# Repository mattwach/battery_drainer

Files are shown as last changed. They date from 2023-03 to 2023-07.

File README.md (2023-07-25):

# battery_drainer

This project describes hardware to safely discharge batteries to a user-chosen
level.

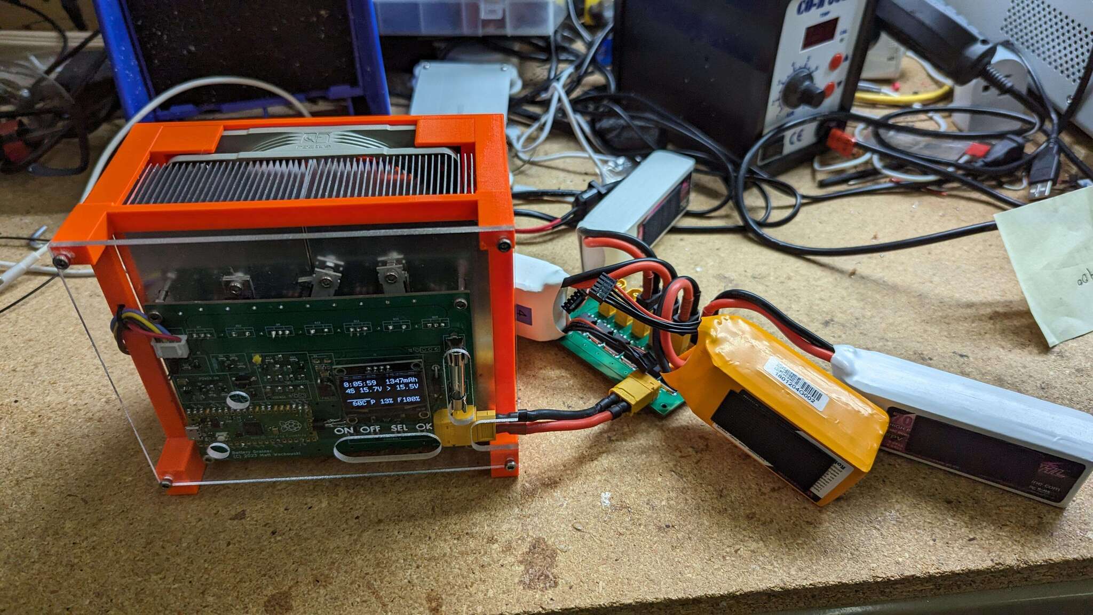
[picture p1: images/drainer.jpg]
Drainer


# Why?

Before I started flying RC models (many years ago), the concept of managing
batteries was off my radar.  While in the hobby, it became clear that proper
management makes a big difference in how long batteries last and how much power
they will deliver.

Storing lithium ion batteries fully-charged or fully-drained causes them to
degrade permanently.  It's much better to store them in a half-charged state.

Since lithium batteries are used basically everywhere (phones, tools, laptops,
    cars, on and on), being aware of these concepts can help you keep more of
your devices running longer and more healthy.

Many non-lithium batteries have "memory effects" and can benefit from a deep
discharge now and then.  See your particular battery type for details on how to
maintain/restore it.

Other applications for discharging include testing battery capacity and
preparing it for disposal.

# Caution

Following anything written in this document is at-your-own risk.

Batteries are energy storage devices and thus carry an inherent risk.  If you
are not familiar with the battery type you are working with, take a few moments to
educate yourself on recommended handling practices.

When working with an untested unit or new batteries, I suggest extra caution.
For example doing initial testing outside on concrete or in a fire pit.

This design incorporates a protection fuse.  I recommend using the
*smallest-sized fuse* that meets your requirements.  If anything goes wrong
with the firmware, a hardware component, or the hardware build, the fuse will
limit the maximum current that can flow.  Starting with a small fuse and
upgrading it later could be a good verification strategy.

# Pre-existing Market Solutions

If you look up "LIPO Battery Discharger" on Amazon or similar, you will find a
variety of products.  These might work for you but note that the project I am
describing has some advantages over what you can buy:

1. Higher maximum power.  The unit I built is running great at 350W.  The components
   I chose are speced to 460W and 30A.  Since you are building it yourself,
   you can choose a transistor/cooling combo that supports the power dissipation
   you need.
2. Support for "safe" multiboards.  My project has a diode-protected multiboard
   that allows you to safely plug in multiple batteries that are at different 
   discharge levels. This protection requires the discharger account for the 
   voltage drop across the protection diodes, which commercial charges do not
   typically do.
3. Support of 1S packs.  Many chargers have a 2S minimum.
4. Lots of customization.  My project lets you customize voltages and
   create special profiles.  For example, I have one that takes packs down to
   4V/Cell, which is useful for packs that I want ready-to-use in worklights and tools.
5. Detailed status.  The OLED of this project gives lots of information
   during the discharge which can help you guage the health of the pack.
6. Support for more battery types than just LIPO, due to the extensive 
   customization ability.

# Using

## User Interface

The unit has four UI buttons: On, Off, Select and OK.

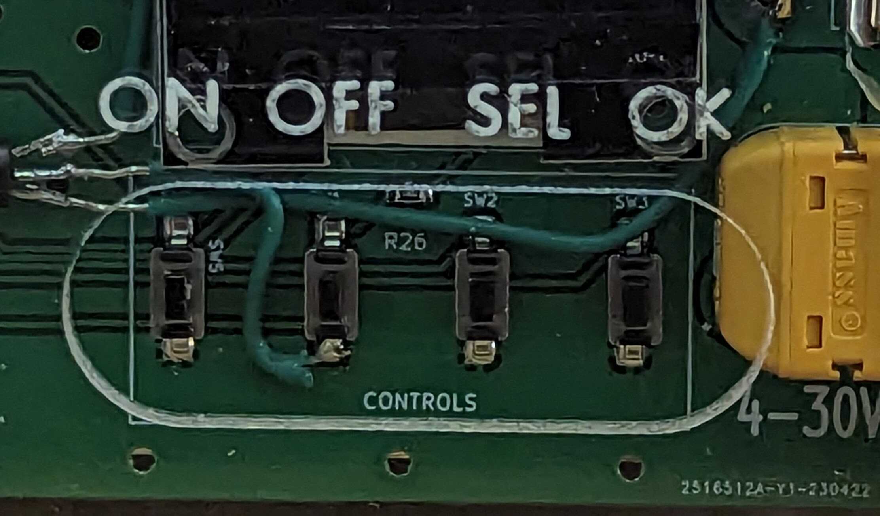
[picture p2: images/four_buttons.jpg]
four buttons


When the device is initially powered up, it will display the current voltage,
cell count and the target voltage.  It also shows a scrollable list of
profiles to choose from:

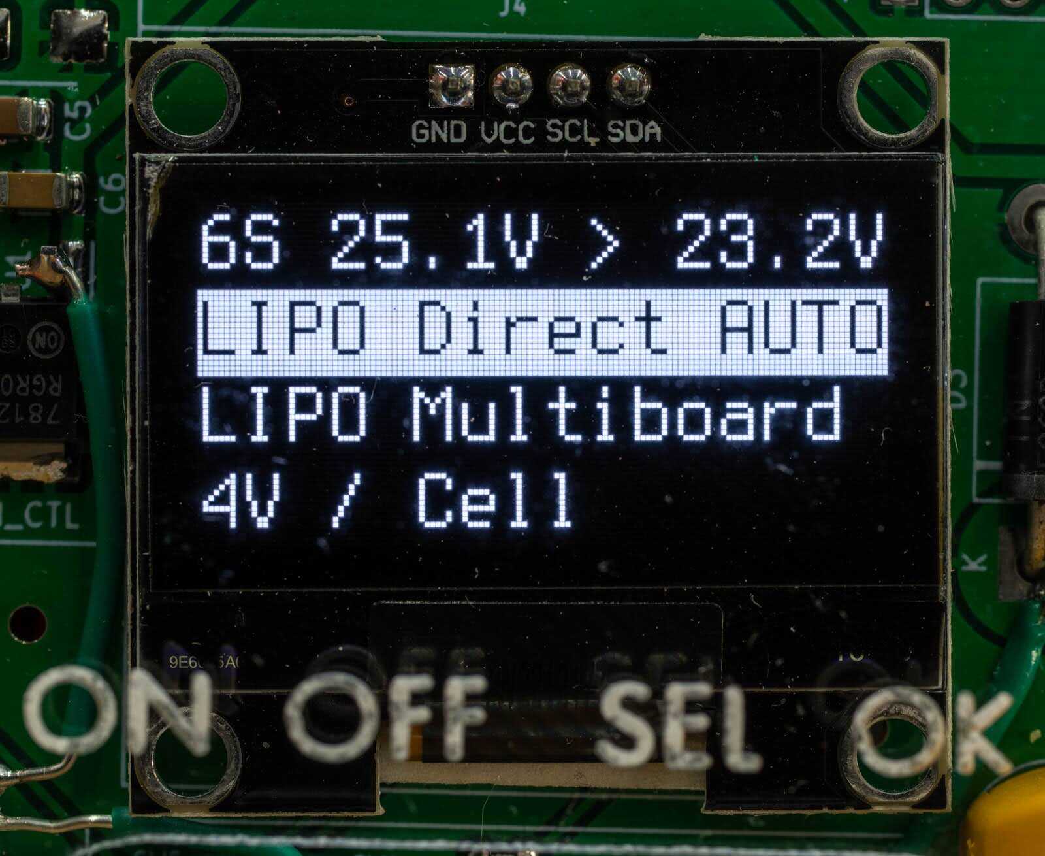
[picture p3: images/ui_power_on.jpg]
ui power on


The user chooses a profile with "Select" and presses "OK" to start discharging.
During discharge, the following status information is displayed (the ghosting
in the image is because the unit was actively updating during the photo):

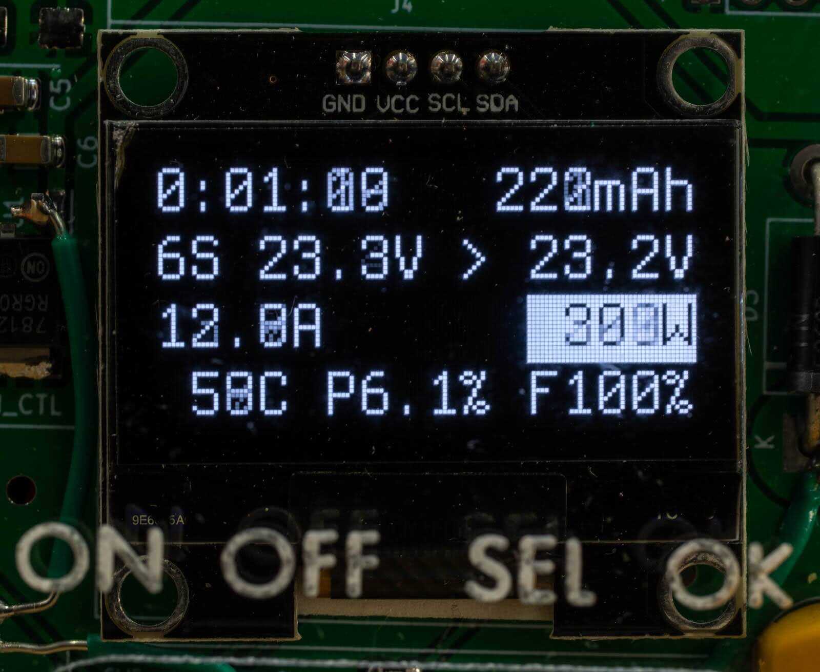
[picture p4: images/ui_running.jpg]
ui running


Information shown includes:

* Time running
* Number of mAH discharged so far
* Battery voltage and cell count
* Target voltage
* Discharge Current
* Power (Voltage * Current)
* Temperature
* FET power level %
* Fan power level %

If the FET power level is limited < 100%, then the parameter that is limiting
the power is highlighted as inverse text.  In the example above, this limit is
overall power draw.  A lower-cell-count battery might hit the max current
instead.  A small battery might be limited by voltage sag.  A hot day might
introduce a temperature limit.  All limits are user configurable - but you'll
need to be aware of what your built hardware can handle and test higher limits
with due caution.

When the discharge is complete, the unit will show some stats for a configurable
amount of time before automatically shutting down.  Here is an example:

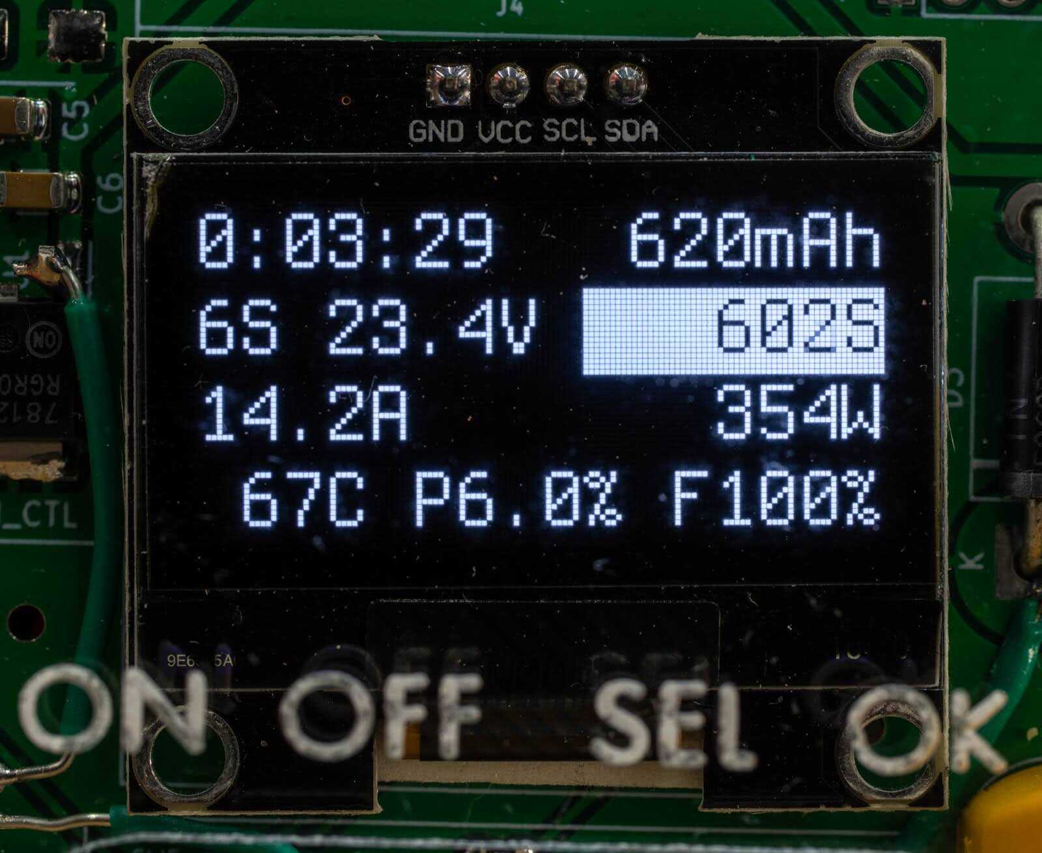
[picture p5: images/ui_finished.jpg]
ui finished


After shutdown, the unit takes very little power (a few microamps) to avoid
further unintended drainage of smaller packs.

## Configuration

Profiles can be edited by connecting a computer to the unit via USB and starting
a terminal program.  On my Linux laptop, I used:

    minicom -b 115200 -P /dev/ttyUSB0

Refer to the [dedicated configuration guide](configuration.md) for details
about how to configure settings, calibrate the device and create/edit profiles.

# Building

## Parts list

To see the parts list, open up the schematic in KiCad and look at the "Symbol
Fields Table".  It looks like a spreadsheet icon in the UI.  Here you will find
a list of parts and links for building an order.  Here is a snapshot of what
the list looked like at some point:

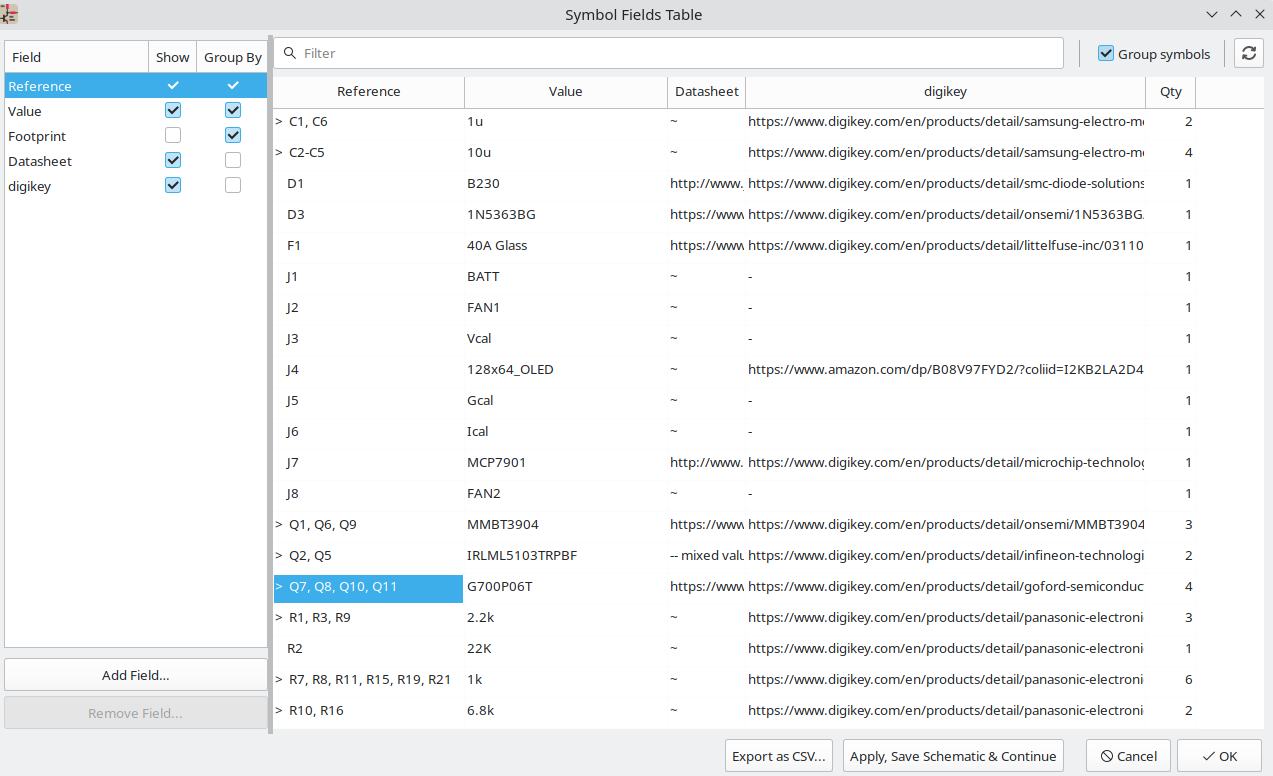
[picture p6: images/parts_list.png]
parts list


## Schematic Overview

Note that the images below are a snapshot of the schematic and not fully
up-tp-date.  See the KiCad original for the latest design.

Here is the complete design (click to expand):

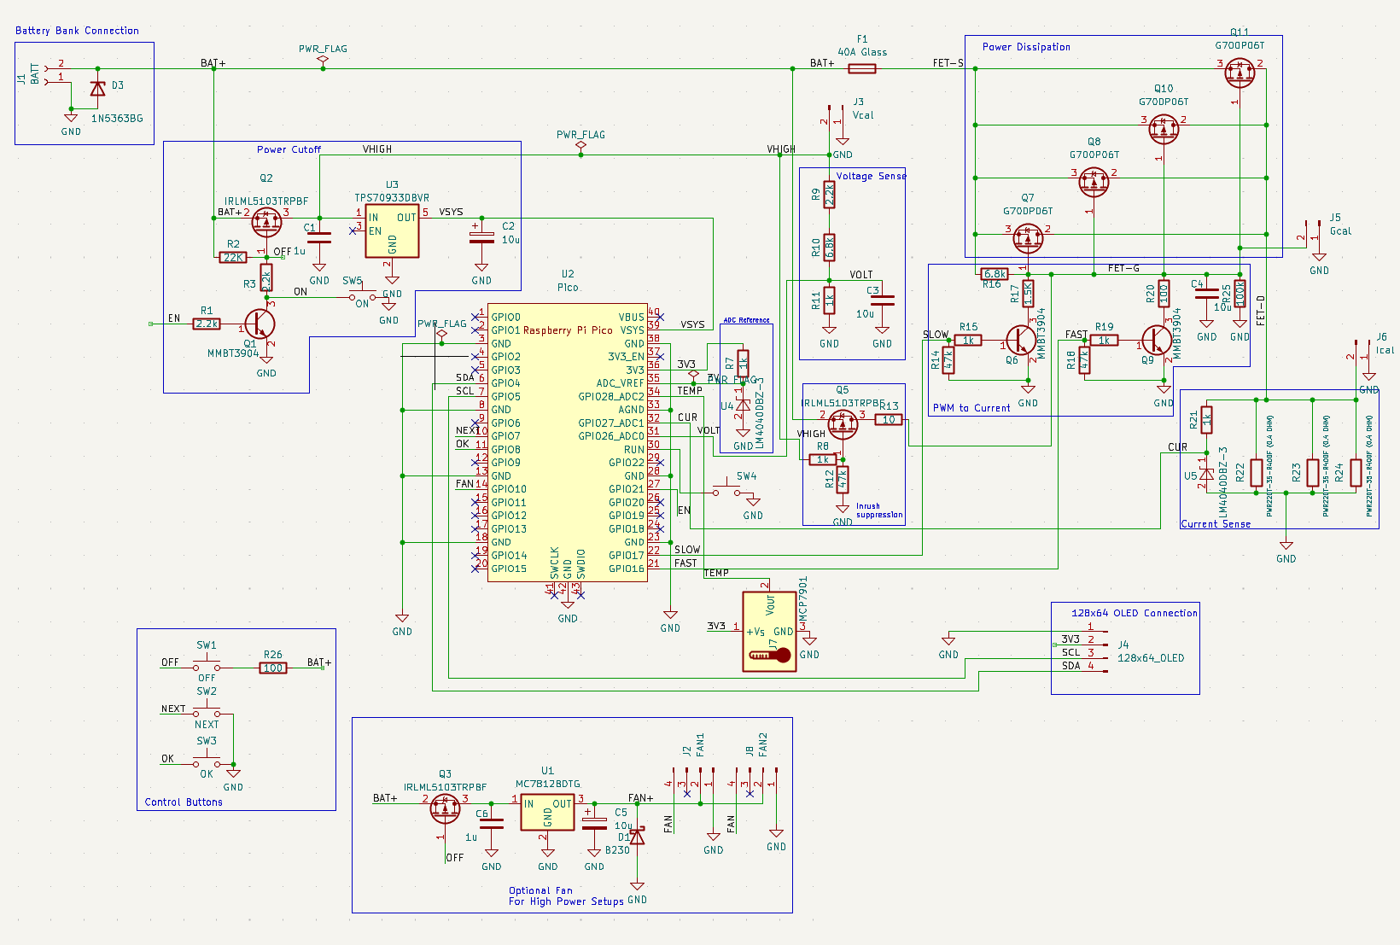
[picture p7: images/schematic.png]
schematic


Here is an early Falstad simulation that gives a basic idea of how the circuit
works:

https://tinyurl.com/2qg4xwyj

There is much going on here.  The sections below break down and explain one
subcircuit at a time.

### Power Dissipation

[Falstad model](https://tinyurl.com/28p9fv3n)

This is a set of 4 P-Channel MOSFETs connected in parallel:

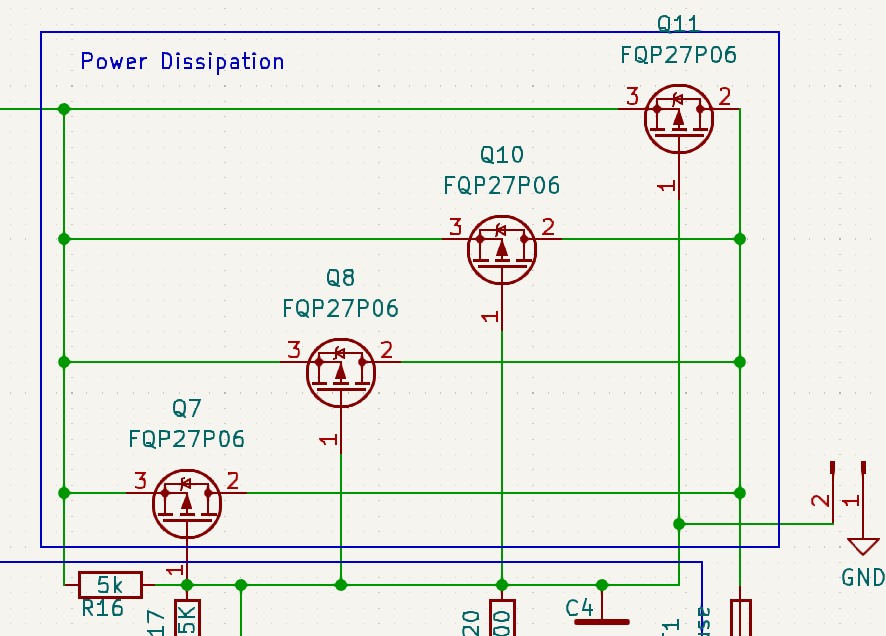
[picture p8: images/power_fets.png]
power FETs


More or less *could* also work.

**Note** The schematic shows four PFETs in parallel.  The unit *I actually
built* uses a single high-power FET instead.  I think that four PFETs would
still work but have not confirmed it.  The main risk of using 4 is that they
will be unevenly loaded to the point where one of them is damaged.  I do
believe that they will be unevenly loaded at lower currents but not after the
current ramps up enough to matter.  Again, I have not confirmed this.  Using a
single high-power FET is my recommendation if you want to play it safer.

The FETs in this design are (unusually) run in their "Ohmic" region which
is controlled by the gate-to-source voltage (Vgs) as exampled in the FQP27P06
datasheet graph below:

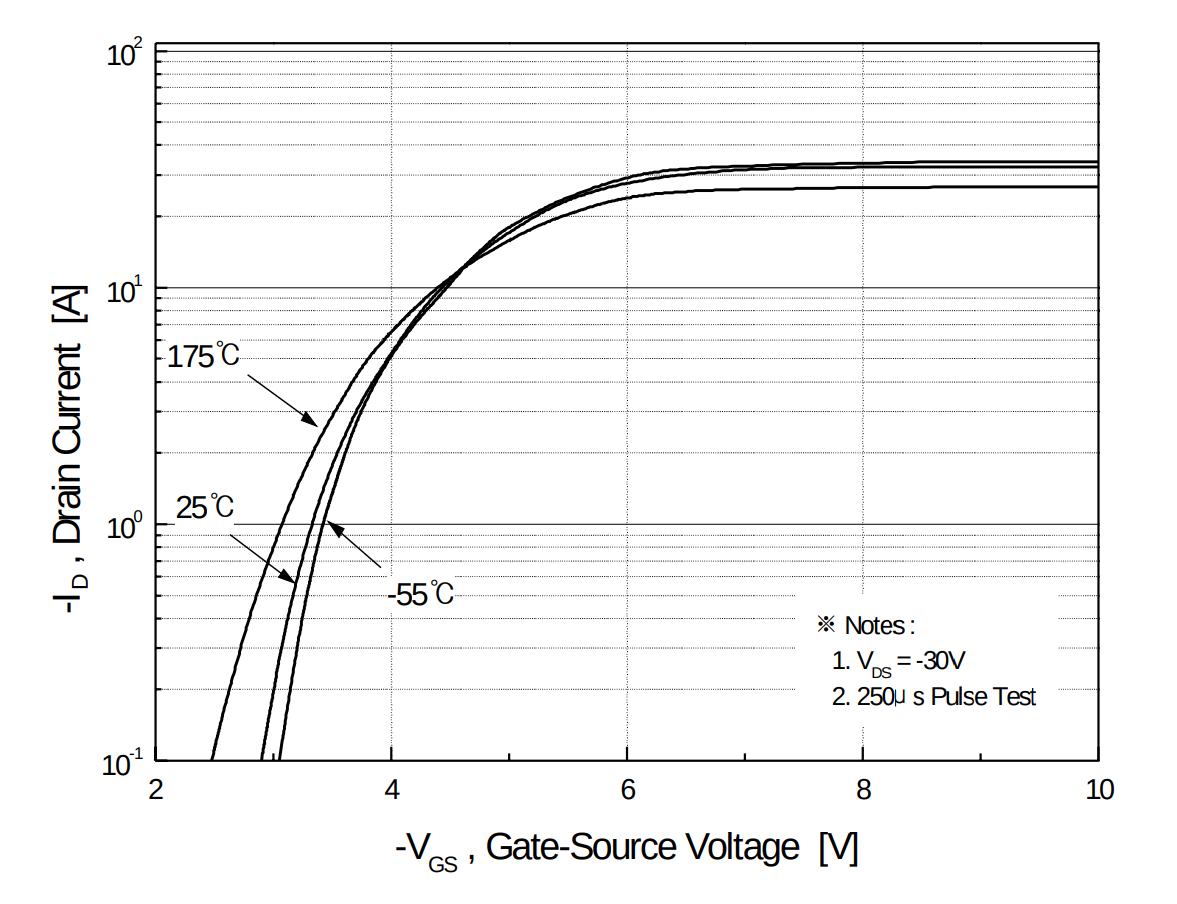
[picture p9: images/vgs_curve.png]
vgs curve


### Vgs Control

[Falstad model](https://tinyurl.com/2bj46fut)

To achieve the target Vgs for the FETs, we the following circuit:

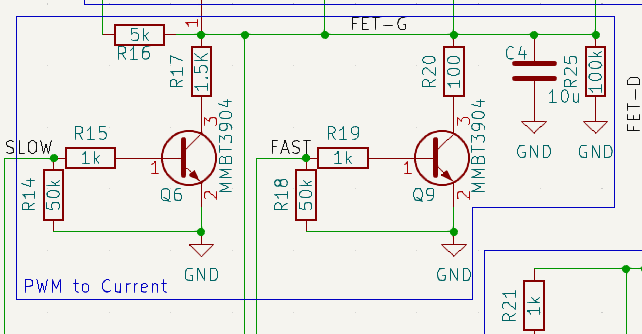
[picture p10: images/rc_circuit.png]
rc circuit


The main element here is the 10u capacitor on the right side of the image.
The voltage across this capacitor is the gate voltage that
each FET will see.

Filling the capacitor is the 5k resistor, R16.  If only this resistor and the
capacitor existed, then the RC constant would be 5000 * 10e-6 = 50ms.  When the
capacitor is sufficiently charged, the FETs will be turned off.

The two transistors (Q6, Q9) are used to drain the capacitor.  The one on the
left is a "slow" drain and the one on the right is a "fast" drain.  The size of
the resistors (R17 and R20) determines the drain speed.  A microcontroller
feeds in a PWM to open/close the transistor.  The duty cycle of this PWM
signal determines how much current is pulled on average and the frequency
of this PWM signal determines how smooth/stable the voltage will be.

The reason for two drains (verses one) is to support a larger voltage
range.  At lower voltages (4V), the FAST drain circuit is needed
to get the Vgs lower than the SLOW drain can achieve.  For higher voltages
(25V), the SLOW drain provides better control resolution.  Depending on the
FET you go with and voltage range you want to support, a single drain
may work fine.

In the power-on state, we can assume that SLOW and FAST are not driven at all
(high Z).  In this state the two 50k pulldown resistors (R14, R18) turn off Q6
and Q9 causing the capacitor to fill up and turn off the main power FETs.

The 100K pull down resistor (R25) slowly drains the capacitor so that it at a known
voltage (0V) when the unit is unplugged and idle.

## Inrush protection

[Falstad model](https://tinyurl.com/2y8c54c8)

On initial battery plug-in, the 100ms or so it takes the capacitor (C4) to
charge via R16 could allow a high current to pass through the FETs for that
time period.  This is mitigated by the following inrush protection circuitry:

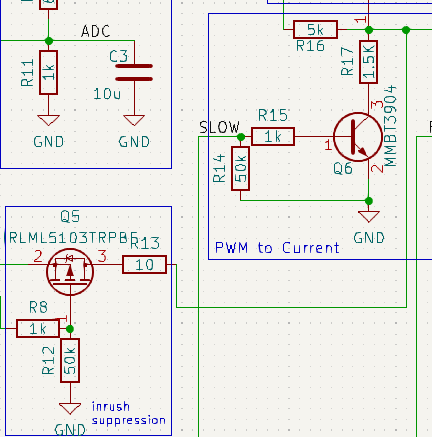
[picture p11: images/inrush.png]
inrush


Fully understanding this block will require studying the full schematic.  A
partial understand can be gained from the image above and the Falstad model.  We
basically have another way to fill the capacitor C4 which is "enabled" when the
battery is plugged in but the user has not pressed the power button yet.  The
way this works is that the source of the FET Q5 is connected to the battery
and the small 10 ohm R13 allows for a rapid fill.  R8 is connected to the
microcontroller power and is thus grounded on plug-in, turning "on" the
FET.

When the user powers on the device (after the battery is plugged in), there is
voltage near-battery going to R8 which turns off the FET and cuts off R13.

### Current Sense 

[Falstad model](https://tinyurl.com/253e6aln)

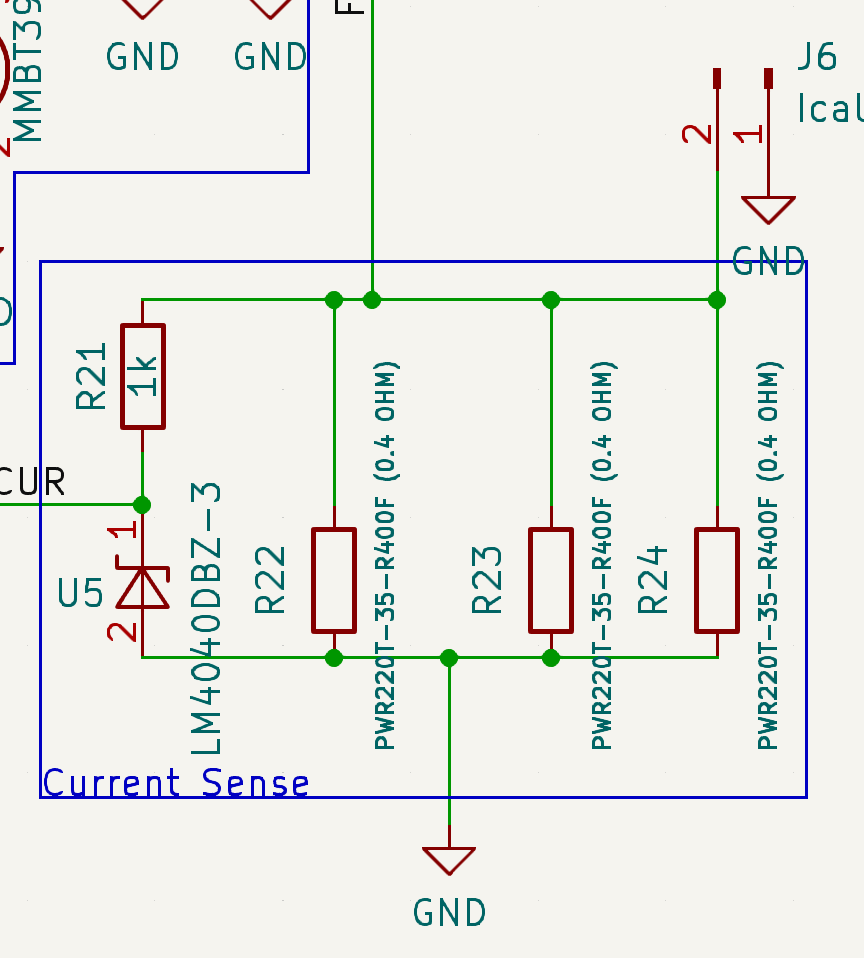
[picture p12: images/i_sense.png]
i sense


One of the four ways the microcontroller decides where to set Vgs is by
monitoring the current flowing through the FETs  (the other three are voltage,
power, and temperature).  An ADC within the microcontroller measures the voltage
across the resistors (R22-R24) then uses Ohm's law (I = V/R) to determine the
current.

Resistor values were chosen for a full 3V swing at 30A of current, this allows
us to use the full 12-bits of ADC resolution for good accuracy.  The downside
is that 3V * 30A = 90W, which is a lot for a resistor to dissipate.  To support
this, I chose 3 35W 0.4 ohm resistors connected in parallel for a total dissipation
capability of ~100W and an equivalent resistance of 0.133 ohm.  Potentially
wasting this much power on a current measurement would normally be frowned upon but
in this application it's actually helping take some load off the main power FET.

A Zener diode (U5) is used to protect the ADC of the microcontroller in the
event that the divided voltage is too high (> 3V).  This is a protection
feature that serves no function under "normal" operating conditions.

### Protection Fuse

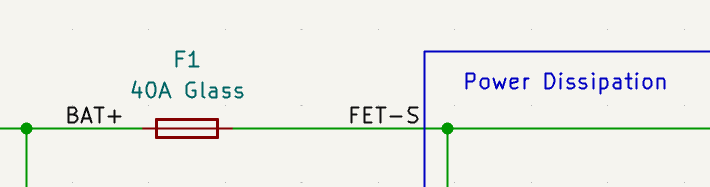
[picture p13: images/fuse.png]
fuse


We also have a protection fuse to help protect against software bugs or other
unexpected problems.  More protection would be offered if the fuse were right at
the battery input but this would introduce a further temperature-dependent
voltage drop that would throw off the voltage measurement.  The "unprotected"
components are the digital logic which should be low current draw barring a
physical issue with the board (< 100 mA)

### Voltage Sense

[Falstad model](https://tinyurl.com/2aavu5hb)

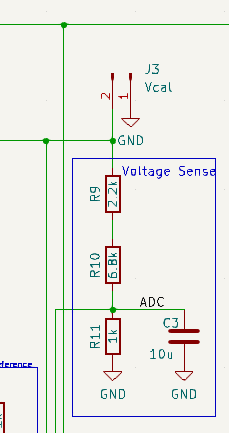
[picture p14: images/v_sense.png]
v sense


The microcontroller monitors the overall battery voltage to determine a sag
value and to determine when the drain process is completed.

The circuit is a simple voltage divider with a capacitor to help stabilize the
reading.

Sag is determined by periodically turning off the FETs (say for one second every
15 seconds) and measuring the "unloaded" voltage of the pack.  This can then be
used a reference value to determine the sag.

The voltage at R9 is not exactly the battery voltage as it has to pass through a
a diode and FET.  The software provides a calibration value to account for this
drop.

### Temperature Sense

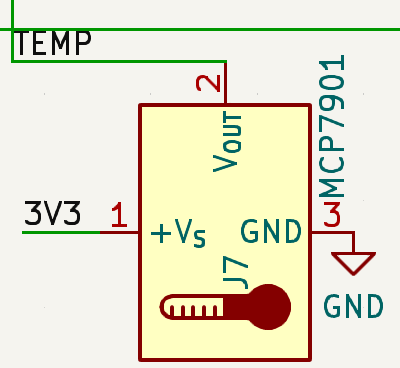
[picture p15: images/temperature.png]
temperature


A temperature sensor is placed against the heatsink and as-close-as-possible to
the FET to monitor the FET temperature.  This feedback can be used to control a
cooling fan (described below) and, if this is inadequate, reduce the current draw.

### Power cutoff

[Falstad model](https://tinyurl.com/22wuu5mp)

The battery drainer is designed to draw nearly zero power (outside of parasitic
losses) when it is off, including after the discharging has completed.  Thus the
user can leave the unit unattended (assuming the needed precautions have been
taken) without concern of parasitic drain.

This is implemented with the following circuit:

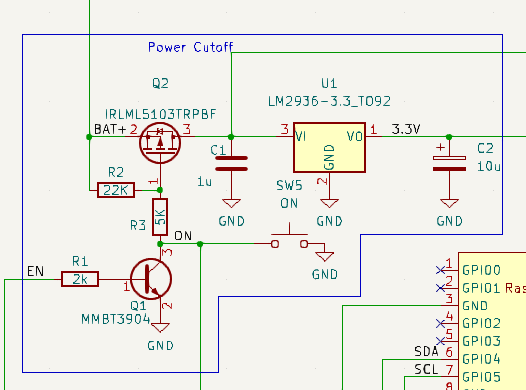
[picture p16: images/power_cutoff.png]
power cutoff


The Q2 FET is key.  It determines if the microcontroller gets any power.
Q2 is off by default, turned off by R2.  There are two ways to turn it on:

1. If the user presses SW5
2. If the microcontroller activates Q1 via "EN".  The microcontroller does
   this as soon as it can (in a split second) and holds it high until the
   microcontroller decides that it is time to power down OR the user presses
   the "OFF" button which forces Q2 off.

### ADC reference

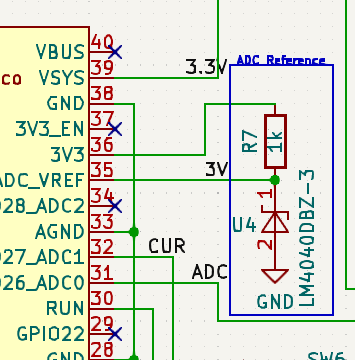
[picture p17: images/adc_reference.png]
adc reference


When using an ADC, one can typically choose from several different sources for
the calibration with the internally-generated 3.3V source as the most
convenient.  The downside of choosing this source is mediocre accuracy.

This design uses the alternate `ADC_VREF` input with a `LM4040` voltage reference
to allow for more accurate measurements.

### OLED connection

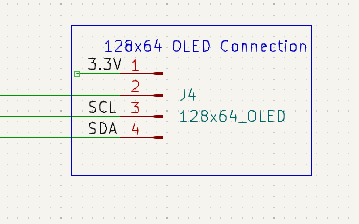
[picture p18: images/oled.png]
OLED


The design breaks out an I2C 4 pin header that is typical for an I2C OLED.  A
128x64 design is the intended unit but anything that supports I2C could be
supported with appropriate firmware modifications.

### Fan connection

The battery drainer effectively converts battery energy to heat, thus you'll need
a cooling strategy to avoid overheating and damaging the discharge circuit.
Like cooling other devices such as CPUs and GPUs, a passive solution is
sometimes adequate and an active solution is often needed.

The circuitry below supports a PWM-based fan controller.

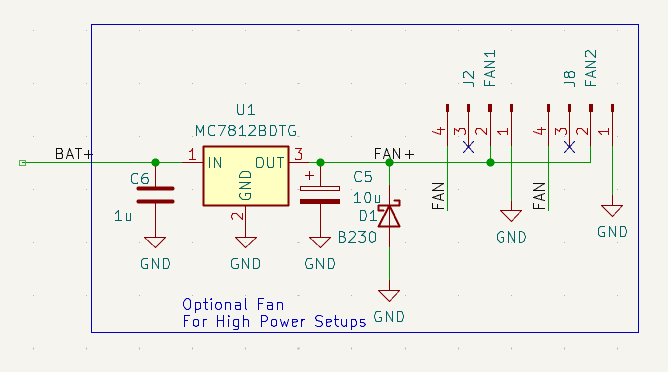
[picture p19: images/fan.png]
fan


The circuit is just a 12V linear regulator with supporting capacitors.  The
connections support "PWM" style PC case fans which generally accept a 25Khz
PWM signal on pin 4.

A flyback diode is needed when powering generic motors but is unlikely to be
needed here as PWM-controlled motors usually already have one in the motor
control circuit.  You can add one for peace-of-mind if you choose.

### PI Pico Microcontroller

As is typical, a microcontroller orchestrates the operation.  Here I chose a PI
Pico because it is inexpensive and quite capable.  It's main downside is the
lack of a low-power sleep mode, but the Power cutoff circuit explained above
compensates for this shortcoming.

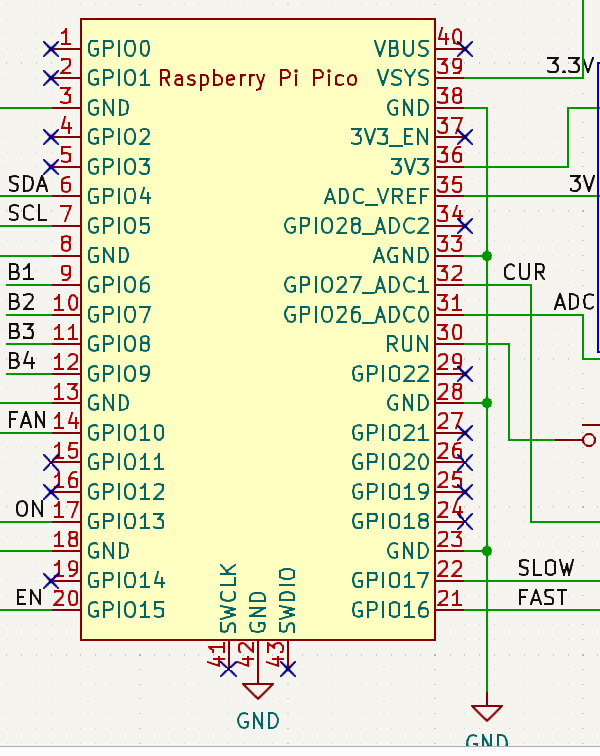
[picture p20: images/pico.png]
Pico


A little bit on the tasks the Pico must attend to:

1. When the unit is powered-up, the Pico must raise the EN pin to keep the power  
   active.  It must lower the EN pin when it is time to shutdown.
2. It controls the dissipation rate of the main FETs via PWM signals on the SLOW 
   and FAST pins.
3. It measures current by ADC decoding the voltage at the CUR pin.
4. It measures the battery voltage via an ADC.
5. It provides an output display via SDA and SCL
6. It controls the fan speed (if present) via the FAN pin.
7. It monitors the buttons Select and OK buttons.

## PCB Layout

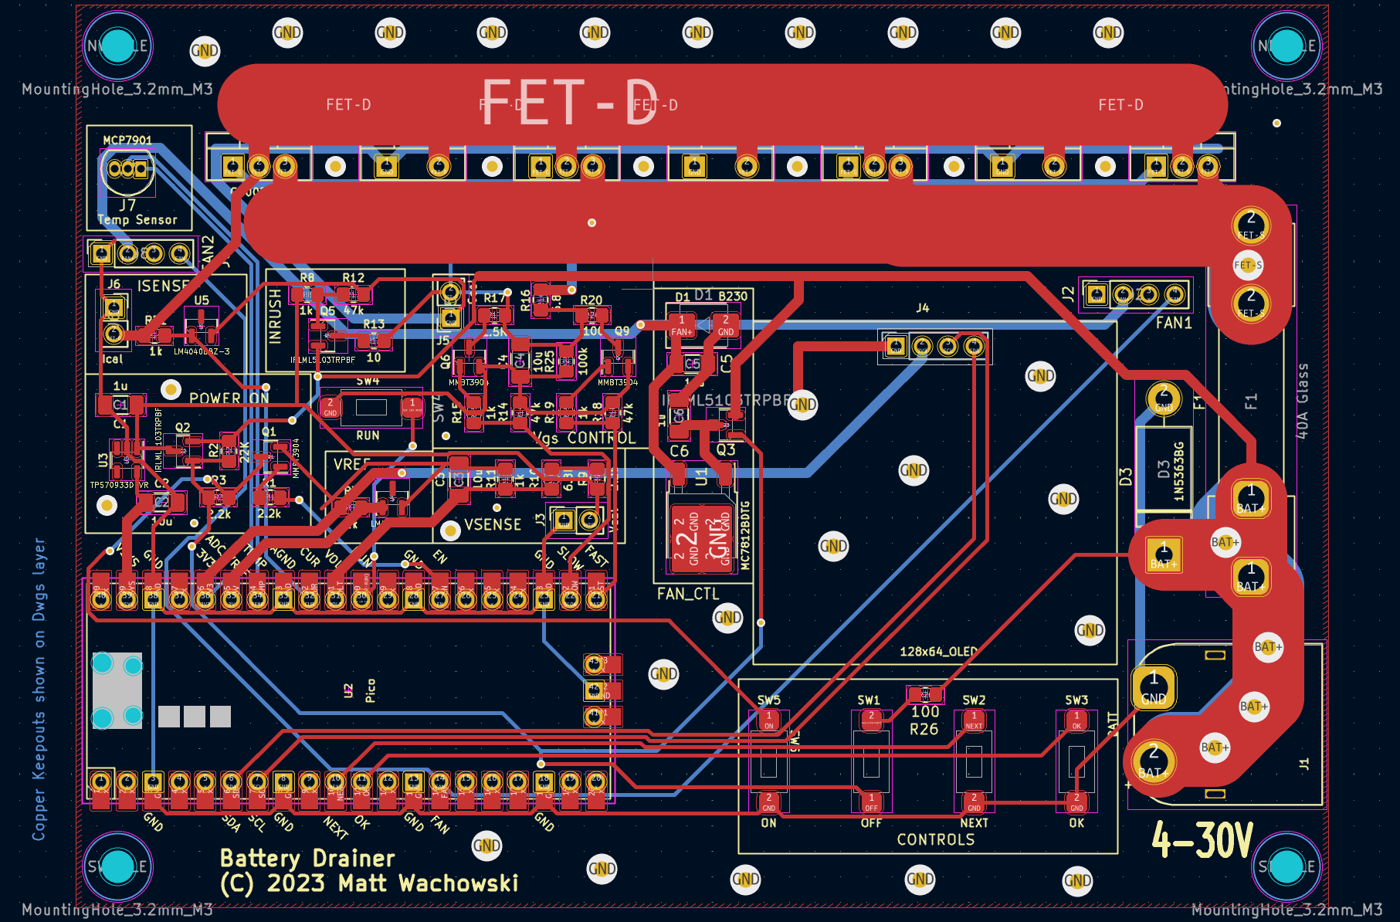
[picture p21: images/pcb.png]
pcb


The PCB layout is above.  Some notes on the layout:

* The dimensions of the board are 122 x 88 mm (4.8 x 3.5 inches)
* Power FETs and resistors are aligned so that a single (large) heatsink can service all of them
* Large traces are used in the higher current areas.
* Large vias are used to try and distribute current and reduce hotspots. 

I went with thicker 2oz copper when manufacturing this board to handle the potentially-large current.

Here are some images of the board, unpopulated and with most components added:

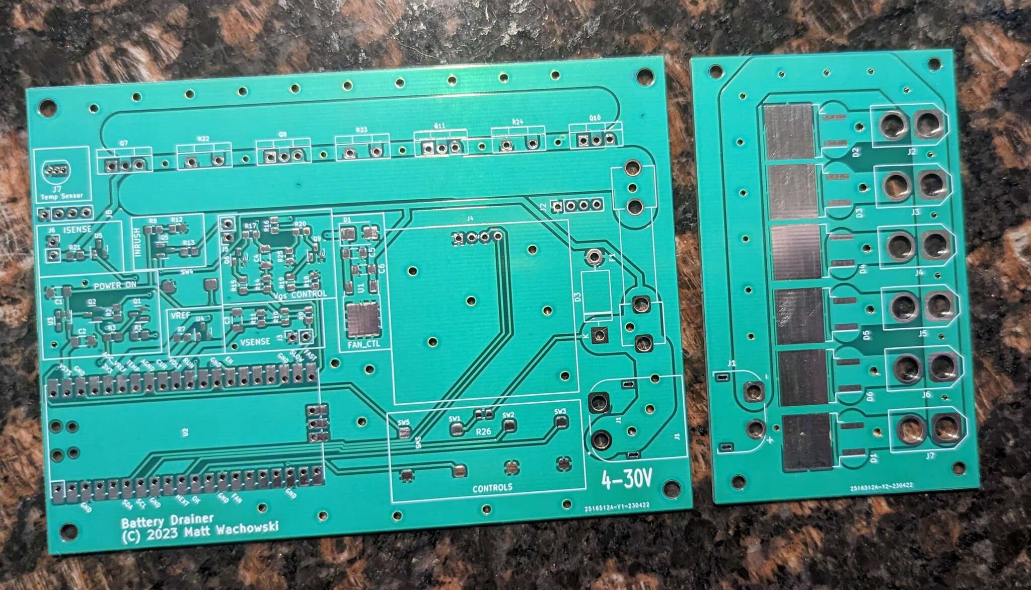
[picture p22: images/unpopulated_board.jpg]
unpopulated


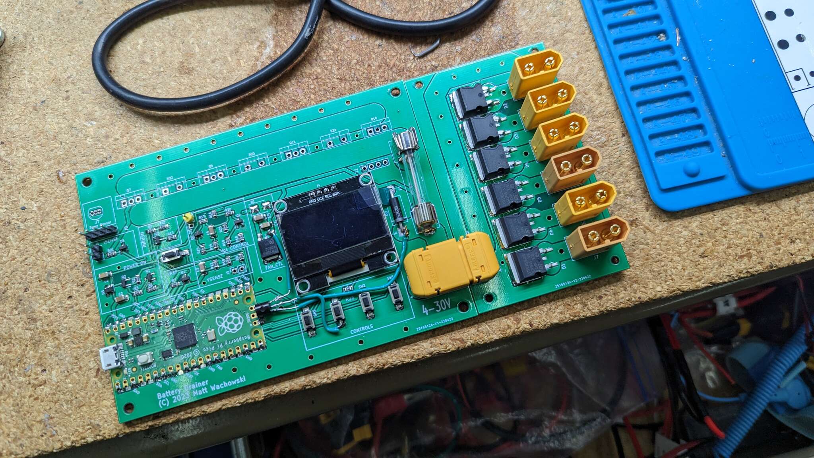
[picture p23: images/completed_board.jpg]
completed


Note that the completed board had a bug where I forgot to add a power-cutoff to
the fan.  If not corrected, this could have caused the fan to draw ~5-10 mA even
after charging is completed.  The fix was to add a PFET (green wires).  The
board design now incorporates the FET on the board.

## Daughterboard

You could plug a single battery into the unit or use a parallel adapter.  Safer
than a parallel adapter would be a board with integrated diodes.  This will
allow batteries of different charge levels to be plugged in without the concern
of large current flows due to unequal discharge levels.  The firmware can
account for the drop across the diodes after the user calibrates the board.  

A bundled example provides connection for 6 XT-60 packs.  Changing the number of
packs or the connector type is of course doable:

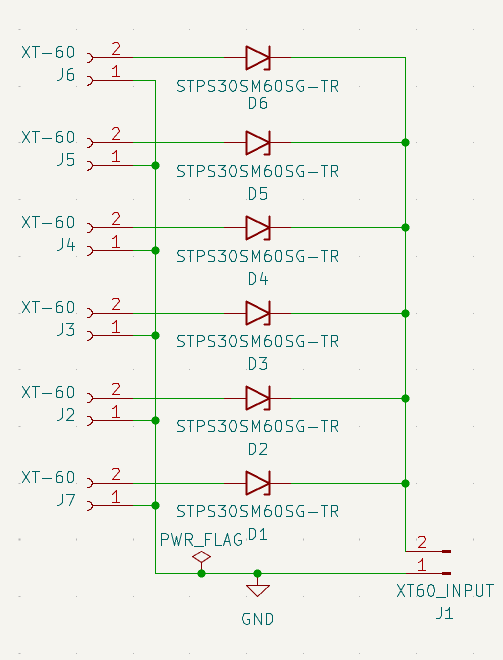
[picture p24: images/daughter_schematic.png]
daughter schematic


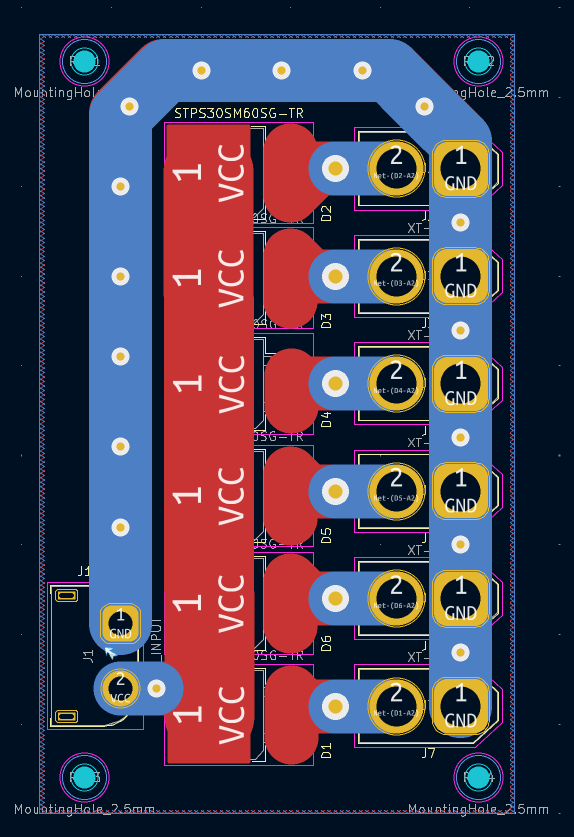
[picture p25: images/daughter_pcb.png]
daughter pcb


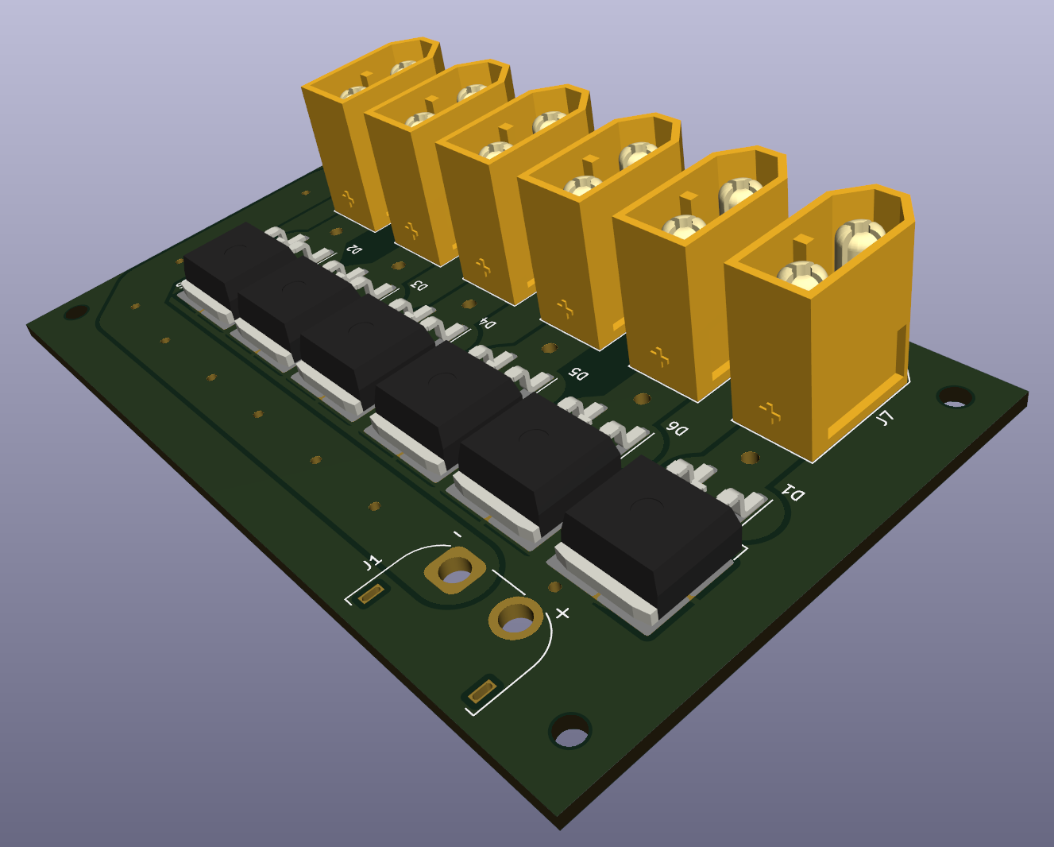
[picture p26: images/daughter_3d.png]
daughter 3d


# Firmware

If you don't want to build the firmware yourself, there is a prebuilt
version [here](https://github.com/mattwach/battery_drainer/tree/main/firmware).

The firmware, `battery_drainer.uf2` is in a standard PI Pico format.  One
way to download it is to mount the Pico as a USB drive and copy over the file.
Refer to beginner PI Pico tutorials for more information, such as
[this one](https://datasheets.raspberrypi.com/pico/getting-started-with-pico.pdf).

If you do not wish to build the firmware yourself, feel free to skip to the
next section.

The firmware is build using a script that wraps the official pico build
system.  To run it, you execute `bootstrap.sh` which exists in [the src/ directory](https://github.com/mattwach/battery_drainer/tree/main/src).

    ./bootstrap.sh
    cd build
    make -j

Let's take a look inside the file:

```
$ cat bootstrap.sh 
#!/bin/bash

if [ ! -f lib/pico_uart_console/CMakeLists.txt ]; then
  git submodule init
  git submodule update
fi

rm -rf build
mkdir build
cd build
cmake ..
```

All standard git and cmake operations which you can execute individually
if you prefer (or are running in an environment where executing `bootstrap.sh`
directory will not work).

# Case Design

For cooling, I ended up going with [2 120x69x36 mm finned alunimum heatsinks](https://www.amazon.com/gp/product/B07TJY3GKP) which cost me $13 each for a
total of $26.  These work great but having to use two is a bit inconvenient, due
to the vertical seam in the center.  I tapped holes in these heatsinks, both
for mounting the board and for holding the FETs, resistors, and temperature
sensors securely to the heat sink (with the aid of thermal paste to complete
the thermal connection).

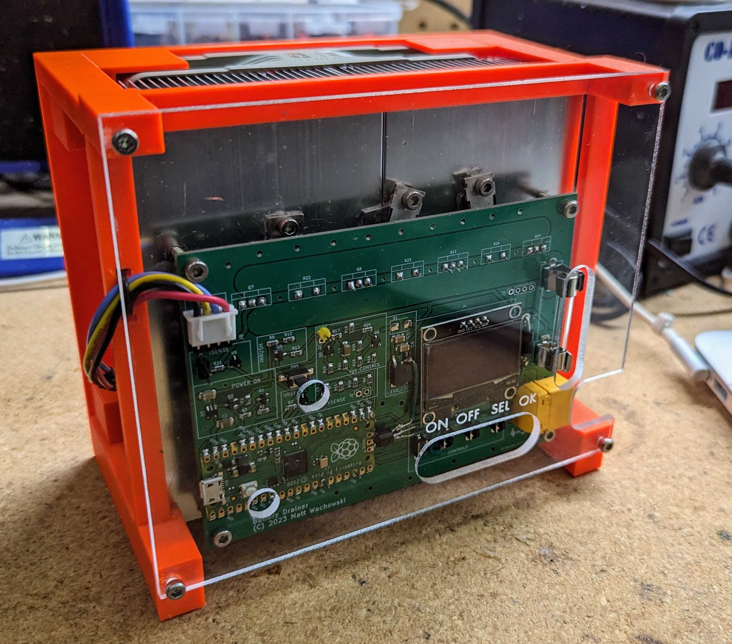
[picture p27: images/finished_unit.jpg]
finished unit


On the backside of the heatsink, I have a 120mm fan which blows air into the
fins.  The microcontroller controls fan speed based on current temperature
and power dissipation.

At first everything was held together with wires.  I wan't sure if a 3D printed
solution would be able to tolerate the dissipated heat.  But after experiencing
with the unit and doing official (temperature probe, IR camera) and non official measurements (finger touch), I determined it would probably be ok.

I ended up designing a case using Open SCAD:

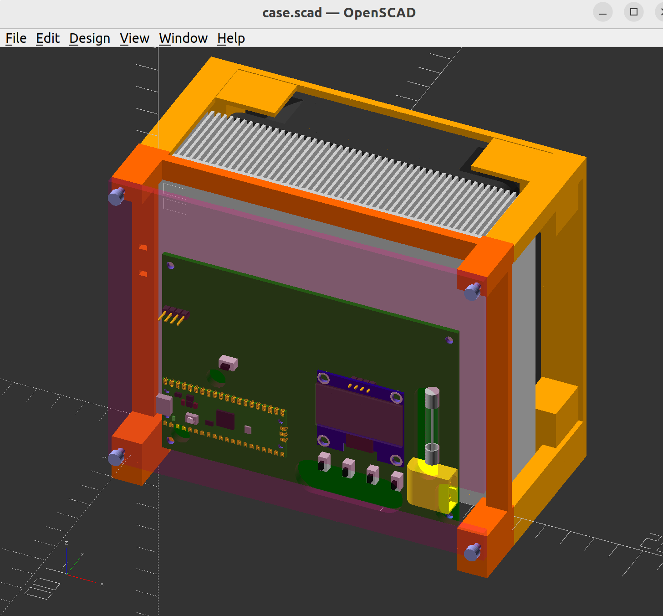
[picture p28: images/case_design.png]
3d printed case


Design files are included with the project [here](https://github.com/mattwach/battery_drainer/tree/main/case).  Ready to print models
are [here](https://github.com/mattwach/battery_drainer/tree/main/case/export).

After many uses, the case is holding up fine with no signs of warping.  Note that I used PETG for the case as PLA has a tendency to "creep" over time, even
at slightly elevated temperatures.

The front plate is acrylic.  I used a 3018 CNC machine to cut it out.  Printing
a cover or making something by hand are of course other options,

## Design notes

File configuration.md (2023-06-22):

## Configuration

Profiles can be edited by connecting a computer to the unit via USB and starting
a termnial program.  On my Linux laptop, I used:

    minicom -b 115200 -P /dev/ttyUSB0

There are two types of configuration: global and profile.

### Global Configuration

Some settings are always used, no matter what profile is selected.

#### Current calibration

The `ical` command is used to calibrate the current measurements.  It's
deault value is 133 milliOhms.  By measuring the current with a multimeter,
you can calibrate this value to match your specific hardware:

    ical 0.130

Would set the resistance to 130 milliOhms 

#### Voltage calibration

With a battery connected, measure the voltage at the vcal test point and enter
it with the `vcal` command.  For example:

    vcal 25.4

Note there is a related `vdrop` parameter but this parameter is  per-profile to
accommodate different breakout boards (e.g. whether they have protection diodes).

#### Voltage sag measurements

You can control how often to take voltage sag measurements.

First is `vsag_interval_seconds` which determines how often to take a baseline
measurement.  For example:

    vsag_interval_seconds 15

Next is `vsag_settle_ms` which determines how long to allow the battery to recover before taking a measurement.  For example:

    vsag_settle_ms 1000

#### Fan Settings

Use `fan_celsius <min_percent> <min_celsius> <max_celsius>` to control any connected fan(s)
At `min_celsius`, the fan(s) will run at `min_percent` and smoothly ramp to
100% speed at and beyond `max_celsius`. Example:

    fan_t 20 40 80 

Use `fan_watts <min_percent> <min_watts> <max_watts>` to control fans by power output.

The settings for `fan_t` and `fan_p` are active at the same time.  Whichever
leads to the higher fan speed at a given moment will be used.

Note that on may fans, using too low of a percent leads to no rotation.

#### Finish Display Time

Use `finish_display <mah_ratio>` to configure the number of seconds
that the finish stats are shown before the unit shuts down.  Example:

    finish_display 0.5

In the example above, if 1000 mAh were pulled from the battery then the display would be active for 1000 * 0.5 = 500 seconds.  If 100 mAh were pulled, then
the display would be active for 100 * 0.5 = 50 seconds.

### Responsiveness

The system looks to open up the FETs as much as possible while keeping under
the current limits of:

* Max voltage sag
* Max current
* Max power
* Max temperature

Thus the goal is to reach one of these maximums while staying under the maximum
for all others.  Which maximum is reached will vary by battery, fan settings, room
temperature, etc.

Coming up with and tuning an optimal PID algorithm that meets the above
requirements would be daunting due to the large number of free variables. For
example we would need to combine all four terms above to define an "error" as a
starting point, then would still need to determine the PID constants.

Fortunately, we do not need to system to converge in minimum time.  By relaxing
this requirement, we can get away with less complex calculations. 

The tuning algorithm is an annealing type algorithm where we use the terms
"velocity" and "acceleration" as a mental model.  As an analogy, imagine trying
to adjust the volume knob on a friend's stereo.  You would likely start with
some gross adjustment until you overshoot the mark, then hunt with increasingly
fine movements until you are satisfied.  If a "loud" commercial comes on,
you will need to adjust it again - again starting a bit fast and fine tuning.

With that in mind, here are the parameters of the algorithm:

* *max_velocity*  The maximum (and starting) velocity in percent / second
* *min_velocity* The minumum allow change velocity in percent / second.
* *deceleration_factor* the amount to decrease the velocity on an overshoot
  (going past the intended mark): from 0 to max_velocity
* *acceleration* the amount to increase the velocity (not reaching
  the intended mark) in percent / second. from 0.0 to max_velocity

Example:

  * fet_max_velocity = 30
  * fet_min_velocity = 0.05
  * fet_deceleration = 0.5
  * fet_acceleration = 0.1

  say the per sample time is 100ms

  The PWM will scale from 0 percent to 100% at 3% per sample, taking 33 samples
  or 3.3 seconds to get there.

  Say instead we hit a limit on the 10th sample.  PWN at this point would
  be 3 * 10 = 30%.  The velocity is reversed and decelerated, becoming
  to (-30 + 0.5) * 0.1 = -2.95% per sample

  On the next sample, PWM will change to 30 - 2.95 = 27.05%  Say that now
  everything is below threshold.  This means that we may have backed off
  too far.  Thus we reverse and decelerate again.  The new velocity becomes
  (29.5 - 0.5) * 0.1 = 2.9% per sample.

  One the next sample, PWM will change to 27.05 + 2.9 = 29.95.  Say that we
  are still too low.  In that case, the acceleration factor kicks in and
  the new velocity is not inverted, becoming (29 + 0.1) * 0.1 = 2.91% per sample.

  and so on.

### Profile Management

#### Create a profile

You can create a profile with the `new` command and a name.  For example:

    new

Profiles are named "New" as a starting point.  Alternately you can duplicate an
existing profile under a new name to use it's settings as a starting point:

    duplicate 0

would take whatever profile is at index zero and copy it under the next
available index.

#### Rename a profile

Change the name of a profile with the `name` command.  e.g.

    name 0 "LIPO 3.8 percell"

#### Delete a profile

Use the delete command with the profile index.  e.g.

    delete 1

#### Move a profile

Move a profile from one index to a different one via `move <source_idx> <dest_idx>`.  e.g.

    move 3 0

#### View profiles

Use the `list` command to view profile names and indexes:

    list

Use the `show` command to view settings for particular indexes or to dump all indexes:

    show
    show 0 2
    show 1 2 3

### Profile Configuration

#### Voltage drop configuration

Use `vdrop <profile_index> <voltage>` to set the voltage difference between the connected
battery and the vcal test point.  This will take into consideration various FETs and
diodes that exist between the two points. Example:

    vdrop 1 0.75

#### Cell count

Use `cell_count <profile_index> <count>` to adjust the number of cells.  If set at zero,
the number of cells will be automatically calculated at start by dividing the voltage
by the `per_cell_target_volts` (see below).  If the automatic calcualtion would lead to incorrect
results in your situation, you'll need to fix the value.

Note that you can also use a value of `1` if you don't want to think in terms of cells
but only the full voltage.  Examples:

    cell_count 1 0
    cell_count 1 1
    cell_count 1 6

#### Target voltage

Sets the per-cell target voltage.  When the target voltage is reached, the unit
will shut off.  For example:

    per_cell_target_volts 1 3.8

Would set the target voltage to 3.8 if `cell_count` is 1, 7.6 if `cell_count` is 2,
etc.

    per_cell_target_volts 1 0.0

Will run the drainer until it can no longer power itself, regardless of the cell count.

#### Damage voltage warning

If the target voltage is set below the `damage_voltage`, the user will be told that
they are about to destroy the connected batteries and will ask for confirmation.
The default settings is for LIPO batteries and is set to 3.3 volts.  Change it
with the `damage_voltage` command:

    damage_voltage 1 3.0

#### Max current

Use `max_amps <profile_index> <current>` to set the maximum allowed current.  Example

    max_amps 1 10.0

#### Max per-cell voltage sag

Use `per_cell_max_vsag <profile_index> <sag>` to determine the maximum amount of 
per-cell voltage sag that is allowed.  For example:

    per_cell_max_vsag 1 0.4

Would allow up to 0.4 * 4 = 1.6V of sag on a 4 cell pack.

#### Max temperature

Use `max_celsius <profile_index> <temp>` to change the maximum allowed heatsink termerature.  Example:

    max_celsius 1 80.0

#### Max Power

Use `max_watts <profile_indx> <watts>` to change the maximum allowed wattage (voltage * current).  Example:

    max_watts 1 150

### Testing

The console provides a `fake_mv` command.  If used, the voltage sense logic will provide that value instead
of the actual voltage reading.  It is useful for doing testing with no battery connected (since you can't
otherwise make it to the charging screen)  Using this setting with a battery connected is not recommended.

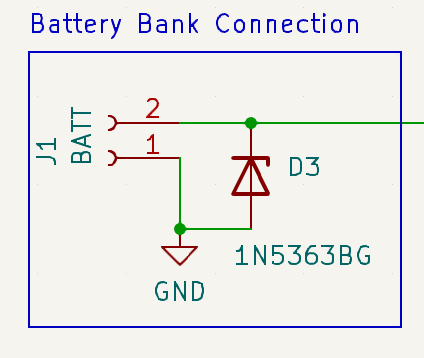
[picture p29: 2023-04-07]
images/inductance.png

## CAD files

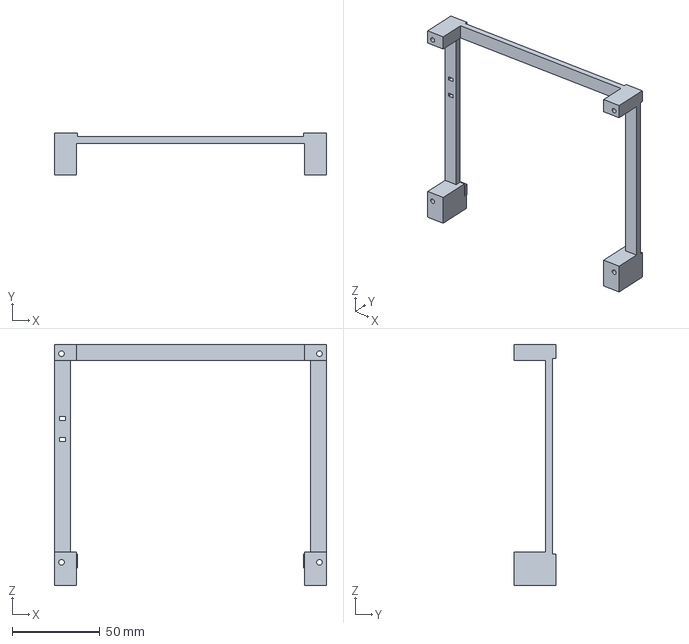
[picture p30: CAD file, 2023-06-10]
case/export/frontside.3mf
154.9 x 24.0 x 137.3 mm

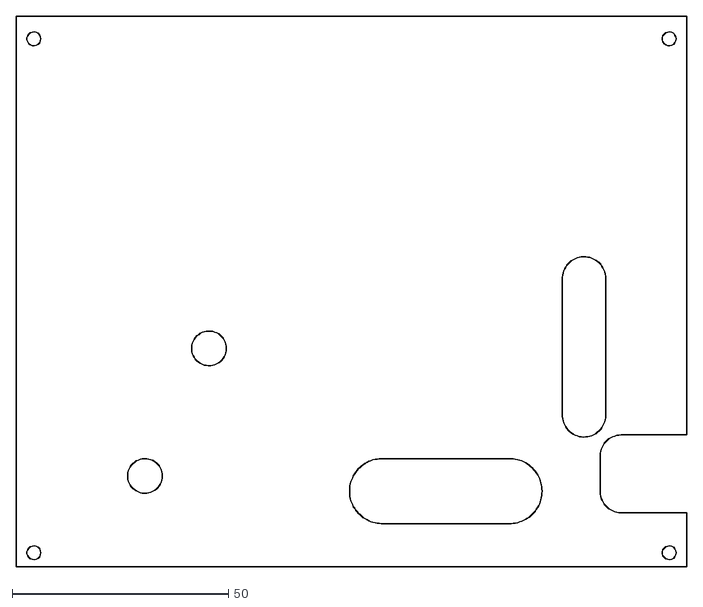
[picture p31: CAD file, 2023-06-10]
case/export/front_plate.dxf
154.9 x 127.3

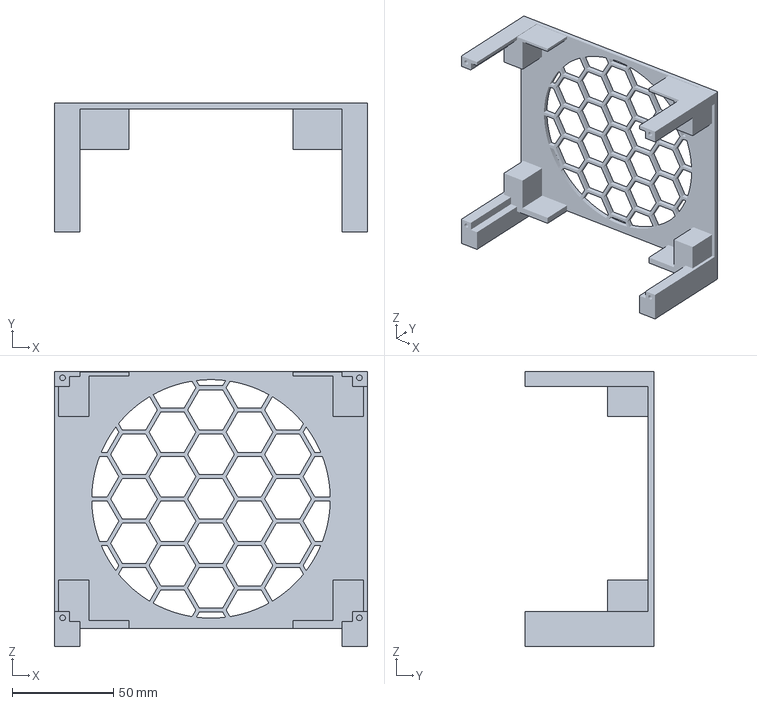
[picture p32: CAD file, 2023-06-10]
case/export/backside.3mf
154.9 x 64.0 x 136.3 mm

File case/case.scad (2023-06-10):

use <lib/mattwach/util.scad>
use <lib/mattwach/honeycomb.scad>
use <lib/mattwach/vitamins/bolts.scad>
include <heat_sink.scad>
include <main_pcb.scad>
include <lib/NopSCADlib/core.scad>
include <lib/NopSCADlib/vitamins/fans.scad>

back_plate_thickness = 3;
cooling_fan_width = 120;
cooling_fan_height = 120;
cooling_fan_thickness = 25;
overlap = 0.01;
heat_sink_mount_xpad = 8;
heat_sink_mount_inset = 5;
heat_sink_mount_depth_inset = 0.01;
heat_sink_mount_depth = cooling_fan_thickness + heat_sink_ysize - heat_sink_mount_depth_inset;
heat_sink_mount_ipad = 0.5;
fan_shroud_gap = 1;
glass_plate_thickness = 3.175;
case_fan_pad = 3;
case_bottom_pad = case_fan_pad + fan_shroud_gap;
case_xsize = heat_sink_xsize + heat_sink_mount_xpad * 2;
case_zsize = heat_sink_zsize + case_bottom_pad + case_fan_pad;
hole_inset_x = heat_sink_mount_xpad / 2;
hole_inset_z = (case_fan_pad + heat_sink_mount_inset + heat_sink_mount_ipad) / 2;
pcb_yoffset = 7;
pcd_plate_gap = 11;
main_plate_width = 9;
front_interface_thickness = 4;
front_foot_height = 10;
front_foot_width = heat_sink_mount_inset + heat_sink_mount_xpad - heat_sink_mount_ipad;
front_foot_depth = 2;
front_post_length = pcb_yoffset + pcd_plate_gap;


module cooling_fan() {
  fan(fan120x25);  
}

module placed_pcb() {
  pcb_xoffset = (heat_sink_xsize - main_pcb_length) / 2;
  translate([
      pcb_xoffset,
      -pcb_yoffset - 6,
      0]) rx(90) main_pcb();
}

module placed_cooling_fan() {
  translate([
      heat_sink_xsize / 2,
      heat_sink_ysize + cooling_fan_thickness / 2,
      heat_sink_zsize / 2]) rx(90) cooling_fan();
}

module assembly() {
  heat_sink();
  placed_cooling_fan();
  placed_pcb();
}

module frontside_mounting_holes(hole_diameter=2.85, hole_depth=15) {
  module hole() {
    ty(-overlap) rx(-90) cylinder(d=hole_diameter, h=hole_depth + overlap);
  }

  module row() {
    tx(hole_inset_x) hole();
    tx(case_xsize - hole_inset_x) hole();
  }

  tz(hole_inset_z) row();
  tz(case_zsize - hole_inset_z) row();
}

module backside() {
  module back_plate() {
    module plate() {
      cube([case_xsize, back_plate_thickness, case_zsize]);
    }

    module fan_hole() {
      fan_hole_diameter = cooling_fan_width - 2;
      honeycomb_size = 20;
      translate([
          case_xsize / 2,
          back_plate_thickness + overlap,
          case_bottom_pad + heat_sink_zsize / 2]) rx(90) intersection() {
        cylinder(d=fan_hole_diameter, h=back_plate_thickness + overlap * 2); 
        tz(-0.5) honeycomb([
            fan_hole_diameter * 1.3,
            fan_hole_diameter * 1.3,
            back_plate_thickness + 1], honeycomb_size, 2);
      }
    }

    difference() {
      plate();
      fan_hole();
    }
  }

  module fan_shroud() {
    fan_shroud_inset = 20;
    fan_shroud_depth = 20;
    fan_shroud_width = cooling_fan_width + fan_shroud_gap + case_fan_pad * 2;
    fan_shroud_height = cooling_fan_height + fan_shroud_gap + case_fan_pad * 2;
    fan_shroud_xextend = 24;
    translate([
        (case_xsize - fan_shroud_width) / 2,
        -fan_shroud_depth,
        case_bottom_pad - case_fan_pad - fan_shroud_gap]) difference() {
      tx(-fan_shroud_xextend / 2) cube([
          fan_shroud_width + fan_shroud_xextend,
          fan_shroud_depth + overlap,
          fan_shroud_height]);
      translate([
        case_fan_pad,
        -overlap,
        case_fan_pad + fan_shroud_gap
      ]) cube([
        fan_shroud_width - case_fan_pad * 2,
        fan_shroud_depth + overlap * 4,
        fan_shroud_height - case_fan_pad * 2]);
      translate([
        case_fan_pad + fan_shroud_inset,
        -overlap,
        -overlap
      ]) cube([
        fan_shroud_width - case_fan_pad * 2 - fan_shroud_inset * 2,
        fan_shroud_depth + overlap * 4,
        fan_shroud_height + overlap * 2]);
      translate([
        -overlap - fan_shroud_xextend / 2,
        -overlap,
        case_fan_pad + fan_shroud_gap + fan_shroud_inset
      ]) cube([
        fan_shroud_width + fan_shroud_xextend + overlap * 2,
        fan_shroud_depth + overlap * 4,
        fan_shroud_height - case_fan_pad * 2 - fan_shroud_inset * 2]);
    }
  }

  module heat_sink_mount() {
    translate([
        0,
        -heat_sink_mount_depth,
        case_bottom_pad - case_fan_pad]) difference() {
      cube([
          case_xsize,
          heat_sink_mount_depth + overlap,
          heat_sink_zsize + case_fan_pad * 2]);
      translate([
          heat_sink_mount_xpad - heat_sink_mount_ipad,
          -overlap,
          case_fan_pad - heat_sink_mount_ipad]) cube([
            heat_sink_xsize + heat_sink_mount_ipad * 2,
            heat_sink_mount_depth + overlap * 4,
            heat_sink_zsize + heat_sink_mount_ipad * 2]);
      translate([
          heat_sink_mount_xpad - heat_sink_mount_ipad + heat_sink_mount_inset,
          -overlap,
          -overlap]) cube([
            heat_sink_xsize + heat_sink_mount_ipad * 2 - heat_sink_mount_inset * 2,
            heat_sink_mount_depth + overlap * 4,
            heat_sink_zsize + heat_sink_mount_ipad * 2 + case_fan_pad * 2 + overlap * 2]);
      translate([
          -overlap,
          -overlap,
          case_fan_pad - heat_sink_mount_ipad + heat_sink_mount_inset]) cube([
            heat_sink_xsize + heat_sink_mount_ipad * 2 + heat_sink_mount_xpad * 2 + overlap * 2,
            heat_sink_mount_depth + overlap * 4,
            heat_sink_zsize + heat_sink_mount_ipad * 2 - heat_sink_mount_inset * 2]);
      frontside_mounting_holes();
    }
  }

  module back_feet() {
    module foot() {
      translate([
          0,
          -heat_sink_mount_depth,
          case_bottom_pad - case_fan_pad - front_foot_height]) cube([
            front_foot_width,
            heat_sink_mount_depth + back_plate_thickness,
            front_foot_height + overlap]);
    }

    foot();
    tx(case_xsize - front_foot_width) foot();
  }

  translate([
      -heat_sink_mount_xpad,
      heat_sink_ysize + cooling_fan_thickness,
      -case_bottom_pad]) color("orange") union() {
    back_plate();
    fan_shroud();
    heat_sink_mount();
    back_feet();
  }
}

module frontside() {
  module interface_feet() {
    foot_xsize = heat_sink_mount_xpad + heat_sink_mount_inset;
    foot_zsize = case_fan_pad + heat_sink_mount_inset;
    module foot() {
      translate([
          -heat_sink_mount_xpad,
          -front_foot_depth,
          -case_fan_pad]) cube([
            foot_xsize,
            front_foot_depth,
            foot_zsize]);
    }

    foot();
    tx(case_xsize - foot_xsize) foot();
    tz(case_zsize - foot_zsize) foot();
    tx(case_xsize - foot_xsize) tz(case_zsize - foot_zsize) foot();
  }

  module main_plate() {
    translate([
        -heat_sink_mount_xpad,
        -front_foot_depth - front_interface_thickness + overlap,
        -case_fan_pad]) difference() {
      cube([
          case_xsize,
          front_interface_thickness + overlap,
          case_zsize]);
      translate([
          main_plate_width,
          -overlap * 6,
          -overlap]) cube([
            case_xsize - main_plate_width * 2,
            front_interface_thickness + overlap * 12,
            case_zsize - main_plate_width + overlap]);
    }
  }

  module front_plate_mounting_posts() {
    module post() {
      translate([
          -heat_sink_mount_xpad,
          -front_foot_depth - front_interface_thickness - front_post_length + overlap,
          -case_fan_pad]) cube([
            front_foot_width,
            front_post_length + front_interface_thickness + overlap,
            main_plate_width]);
    }

    post();
    tx(case_xsize - front_foot_width) post();
    tz(case_zsize - main_plate_width) post();
    tx(case_xsize - front_foot_width) tz(case_zsize - main_plate_width) post();
  }

  module front_feet() {
    module foot() {
      translate([
          -heat_sink_mount_xpad,
          -front_foot_depth - front_interface_thickness - front_post_length,
          -case_fan_pad - front_foot_height]) cube([
            front_foot_width,
            front_post_length + front_interface_thickness + front_foot_depth,
            front_foot_height + overlap]);
    }

    foot();
    tx(case_xsize - front_foot_width) foot();
  }

  module fan_cable_tiedown() {
    hole_span = 12;
    module hole() {
      hole_width = 3.5;
      hole_height = 2.25;
      hole_z_offset = 75;
      translate([
          -heat_sink_mount_xpad + (main_plate_width - hole_width) / 2,
          -front_foot_depth - front_interface_thickness,
          hole_z_offset]) cube([hole_width, front_interface_thickness + overlap * 3, hole_height]);
    }

    tz(-hole_span / 2) hole();
    tz(hole_span / 2) hole();
  }
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

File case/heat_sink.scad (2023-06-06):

use <lib/mattwach/util.scad>

heat_sink_xsize = 138.9;
heat_sink_ysize = 36;
heat_sink_zsize = 120.3;

module heat_sink() {
  overlap = 0.01;
  module block() {
    cube([heat_sink_xsize, heat_sink_ysize, heat_sink_zsize]);
  }

  module fins() {
    fin_width = 1.5;
    fin_count = 52;
    fin_depth = heat_sink_ysize - 4.8;

    gap_space = fin_width * fin_count;
    fill_space = heat_sink_xsize - gap_space;
    fill_width = fill_space / (fin_count + 1);

    module fin() {
      translate([
          fill_width,
          heat_sink_ysize - fin_depth,
          -overlap]) cube([
            fin_width,
            fin_depth + overlap,
            heat_sink_zsize + overlap * 2]);
    }

    for (i = [0:fin_count-1]) {
      tx((fin_width + fill_width) * i) fin();
    }
  }

  difference() {
    block();
    color("silver") fins();
  }
}

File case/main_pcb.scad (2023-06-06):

use <lib/mattwach/util.scad>
include <lib/mattwach/vitamins/electronics/buttons.scad>
include <lib/mattwach/vitamins/electronics/fuse.scad>
include <lib/mattwach/vitamins/electronics/oled.scad>
include <lib/mattwach/vitamins/electronics/pi_pico.scad>
include <lib/mattwach/vitamins/rc/xt60.scad>
include <lib/NopSCADlib/vitamins/pin_headers.scad>

main_pcb_length = 121.9;
main_pcb_width = 88;
main_pcb_thickness = 1.8;

module main_pcb() {
  overlap = 0.01;

  module pcb() {
    module mount_holes() {
      holes_xspan = 115;
      holes_yspan = 79.8;
      hole_diameter = 3.2;

      module hole() {
        tz(-overlap) cylinder(d=hole_diameter, h=main_pcb_thickness + overlap * 2);
      }

      module side() {
        txy((main_pcb_length - holes_xspan) / 2, (main_pcb_width - holes_yspan) / 2) hole();
        txy((main_pcb_length - holes_xspan) / 2 + holes_xspan, (main_pcb_width - holes_yspan) / 2) hole();
      }

      side();
      ty(holes_yspan) side();
    }

    module board() {
      color("#070") cube([
          main_pcb_length,
          main_pcb_width,
          main_pcb_thickness]);
    }

    difference() {
      board();
      mount_holes();
    }
  }

  module pico() {
    pico_x_offset = 0.5;
    pico_y_offset = 11;
    translate([
        pico_x_offset,
        pico_y_offset,
        main_pcb_thickness]) pi_pico();
  }

  module oled() {
    oled_x_offset = 65.6;
    oled_y_offset = 23;
    oled_z_offset = main_pcb_thickness + 2.54;
    translate([
        oled_x_offset,
        oled_y_offset,
        oled_z_offset]) oled_128x64_1_5in_i2c(true);
  }

  module xt60_connector() {
    xt60_xinset = 18.4;
    xt60_yinset = 10.5;
    translate([
        main_pcb_length - xt60_xinset,
        xt60_yinset,
        main_pcb_thickness]) xt60_pw_male();
  }

  module buttons() {
    button_width = 3.6;
    module button() {
      tz(main_pcb_thickness) pcb_button(
          length = 6.2,
          width = button_width,
          height = 3.5,
          button_length = 3,
          button_width = 1.5,
          button_height = 2
      );
    }

    module reset_button() {
      reset_button_xoffset = 25;
      reset_button_yoffset = 46;
      txy(reset_button_xoffset, reset_button_yoffset) button();
      
    }

    module control_buttons() {
      control_button_xoffset = 66;
      control_button_yoffset = 11.4;
      control_button_count = 4;
      control_button_xspan = 10;

      for (i = [0:control_button_count-1]) {
        txy(
            button_width + control_button_xoffset + i * control_button_xspan,
            control_button_yoffset) rz(90) button();
      }
    }

    reset_button();
    control_buttons();
  }

  module fuse() {
    fuse_xoffset = 7.2;
    fuse_yoffset = 32;
    fuse_zoffset = 7 + main_pcb_thickness;
    translate([
        main_pcb_length - fuse_xoffset,
        fuse_yoffset,
        fuse_zoffset]) rx(-90) glass_fuse(diameter=5.6, length=32, metal_length=6.4);
  }

  module pins() {
    module fan_pins() {
      pin_centerx = 2.54 * 2 - 2.54 / 2;
      offset_x = 2.5;
      offset_y = 64;
      translate([
          pin_centerx + offset_x,
          offset_y,
          main_pcb_thickness]) pin_header(2p54header, 4, 1);
    }

    fan_pins();
  }

  pcb();
  pico();
  oled();
  xt60_connector();
  buttons();
  fuse();
  pins();
}

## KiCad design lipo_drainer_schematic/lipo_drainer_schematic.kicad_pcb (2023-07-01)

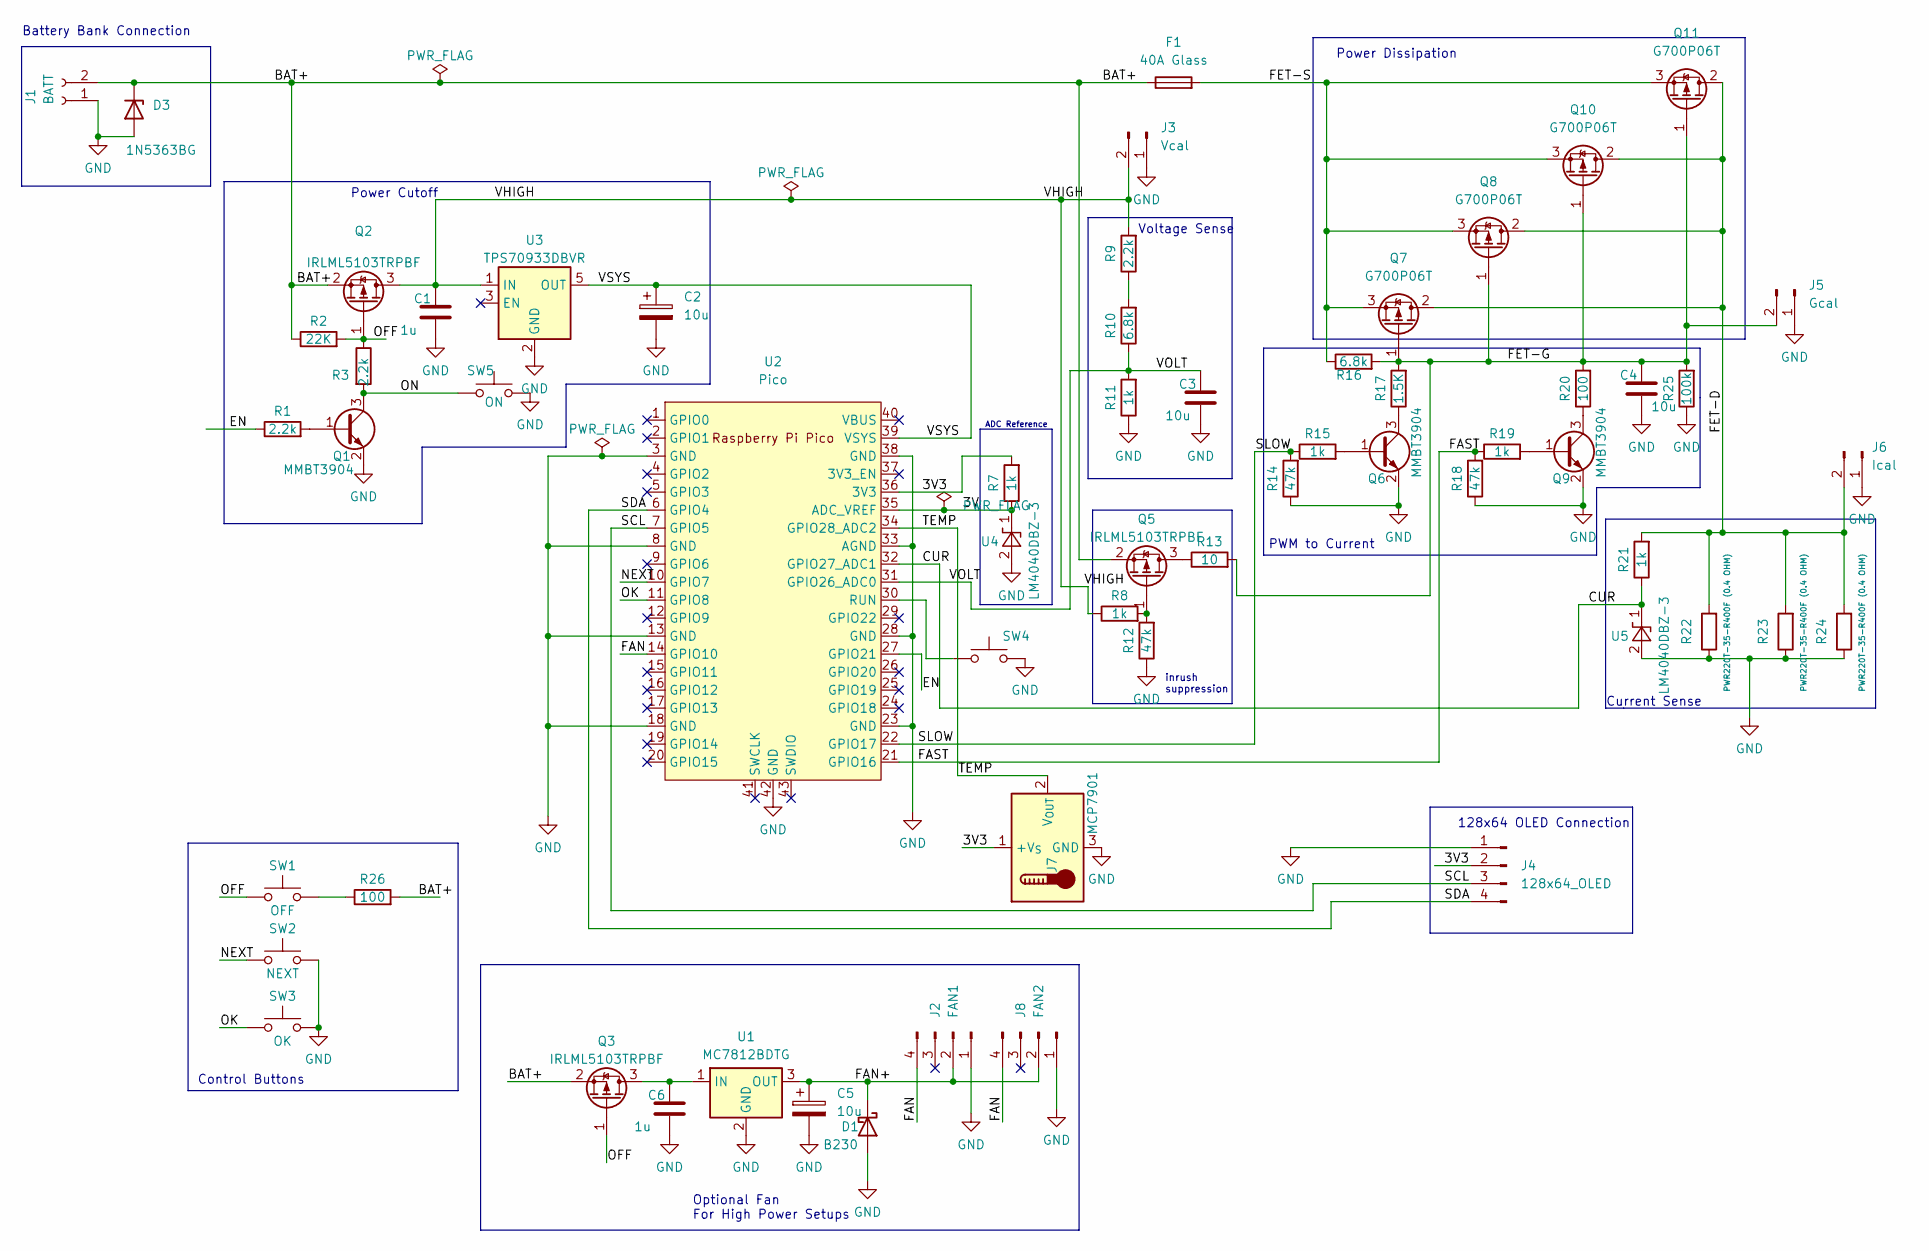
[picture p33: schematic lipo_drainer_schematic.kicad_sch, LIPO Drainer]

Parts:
C1, C6: 1u; C_1206_3216Metric_Pad1.33x1.80mm_HandSolder
C2, C3, C4, C5: 10u; C_1206_3216Metric_Pad1.33x1.80mm_HandSolder
D1: B230; D_SMB
D3: 1N5363BG; D_DO-201AD_P15.24mm_Horizontal
F1: 40A Glass; Fuseholder_Clip-6.3x32mm_Littelfuse_102_Inline_P34.21x7.62m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
J1: BATT; AMASS_XT60PW-M_1x02_P7.20mm_Horizontal
J2: FAN1; PinSocket_1x04_P2.54mm_Vertical
J3: Vcal; PinSocket_1x02_P2.54mm_Vertical
J4: 128x64_OLED; OLED_128_64_1.3in
J5: Gcal; PinSocket_1x02_P2.54mm_Vertical
J6: Ical; PinSocket_1x02_P2.54mm_Vertical
J7: MCP7901; TO-92_Inline
J8: FAN2; PinSocket_1x04_P2.54mm_Vertical
Q1, Q6, Q9: MMBT3904; SOT-23
Q2, Q3, Q5: IRLML5103TRPBF; SOT-23
Q7, Q8, Q10, Q11: G700P06T; TO-220-3_Vertical
R1, R3, R9: 2.2k; R_0805_2012Metric_Pad1.20x1.40mm_HandSolder
R2: 22K; R_0805_2012Metric_Pad1.20x1.40mm_HandSolder
R7, R8, R11, R15, R19, R21: 1k; R_0805_2012Metric_Pad1.20x1.40mm_HandSolder
R10, R16: 6.8k; R_0805_2012Metric_Pad1.20x1.40mm_HandSolder
R12, R14, R18: 47k; R_0805_2012Metric_Pad1.20x1.40mm_HandSolder
R13: 10; R_0805_2012Metric_Pad1.20x1.40mm_HandSolder
R17: 1.5K; R_0805_2012Metric_Pad1.20x1.40mm_HandSolder
R20, R26: 100; R_0805_2012Metric_Pad1.20x1.40mm_HandSolder
R22, R23, R24: PWR220T-35-R400F (0.4 OHM); TO-220-2_Vertical
R25: 100k; R_0805_2012Metric_Pad1.20x1.40mm_HandSolder
SW1: OFF; SMD_Button_6mm_3_5mm
SW2: NEXT; SMD_Button_6mm_3_5mm
SW3: OK; SMD_Button_6mm_3_5mm
SW4: RUN; SMD_Button_6mm_3_5mm
SW5: ON; SMD_Button_6mm_3_5mm
U1: MC7812BDTG; TO-252-2
U2: Pico; RPi_Pico_SMD_TH
U3: TPS70933DBVR; SOT-23-5
U4, U5: LM4040DBZ-3; SOT-23

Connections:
/3V: R7.1, U2.35 (ADC_VREF), U4.1 (K)
/3V3: J4.2, J7.1 (+V_{S}), R7.2, U2.36 (3V3)
/BAT+: D3.1 (K), F1.1, J1.2, Q2.2 (S), Q3.2 (S), Q5.2 (S), R2.1, R26.2
/CUR: R21.1, U2.32 (GPIO27_ADC1), U5.1 (K)
/EN: R1.1, U2.27 (GPIO21)
/FAN: J2.4, J8.4, U2.14 (GPIO10)
/FAN+: C5.1, D1.1 (K), J2.2, J8.2, U1.3 (OUT)
/FAST: R18.2, R19.1, U2.21 (GPIO16)
/FET-D: J6.2, Q7.2 (D), Q8.2 (D), Q10.2 (D), Q11.2 (D), R21.2, R22.2, R23.2, R24.2
/FET-G: C4.1, J5.2, Q7.1 (G), Q8.1 (G), Q10.1 (G), Q11.1 (G), R13.2, R16.2, R17.2, R20.2, R25.2
/FET-S: F1.2, Q7.3 (S), Q8.3 (S), Q10.3 (S), Q11.3 (S), R16.1
/NEXT: SW2.1, U2.10 (GPIO7)
/OFF: Q2.1 (G), Q3.1 (G), R2.2, R3.1, SW1.1
/OK: SW3.1, U2.11 (GPIO8)
/ON: Q1.3 (C), R3.2, SW5.1
/SCL: J4.3, U2.7 (GPIO5)
/SDA: J4.4, U2.6 (GPIO4)
/SLOW: R14.2, R15.1, U2.22 (GPIO17)
/TEMP: J7.2 (V_{OUT}), U2.34 (GPIO28_ADC2)
/VHIGH: C1.1, J3.2, Q2.3 (D), R8.1, R9.2, U3.1 (IN)
/VOLT: C3.1, R10.1, R11.2, U2.31 (GPIO26_ADC0)
/VSYS: C2.1, U2.39 (VSYS), U3.5 (OUT)
GND: C1.2, C2.2, C3.2, C4.2, C5.2, C6.2, D1.2 (A), D3.2 (A), J1.1, J2.1, J3.1, J4.1, J5.1, J6.1, J7.3 (GND), J8.1, Q1.2 (E), Q6.2 (E), Q9.2 (E), R11.1, R12.1, R14.1, R18.1, R22.1, R23.1, R24.1, R25.1, SW2.2, SW3.2, SW4.2, SW5.2, U1.2 (GND), U2.3 (GND), U2.8 (GND), U2.13 (GND), U2.18 (GND), U2.23 (GND), U2.28 (GND), U2.33 (AGND), U2.38 (GND), U2.42 (GND), U3.2 (GND), U4.2 (A), U5.2 (A)
unnamed: Q1.1 (B), R1.2
unnamed: C6.1, Q3.3 (D), U1.1 (IN)
unnamed: Q5.3 (D), R13.1
unnamed: Q5.1 (G), R8.2, R12.2
unnamed: Q6.1 (B), R15.2
unnamed: Q6.3 (C), R17.1
unnamed: Q9.1 (B), R19.2
unnamed: Q9.3 (C), R20.1
unnamed: R9.1, R10.2
unnamed: R26.1, SW1.2
unnamed: SW4.1, U2.30 (RUN)

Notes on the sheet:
inrush suppression
Battery Bank Connection
Control Buttons
Power Dissipation
Optional Fan For High Power Setups
Current Sense
ADC Reference
Voltage Sense
PWM to Current
Power Cutoff
128x64 OLED Connection

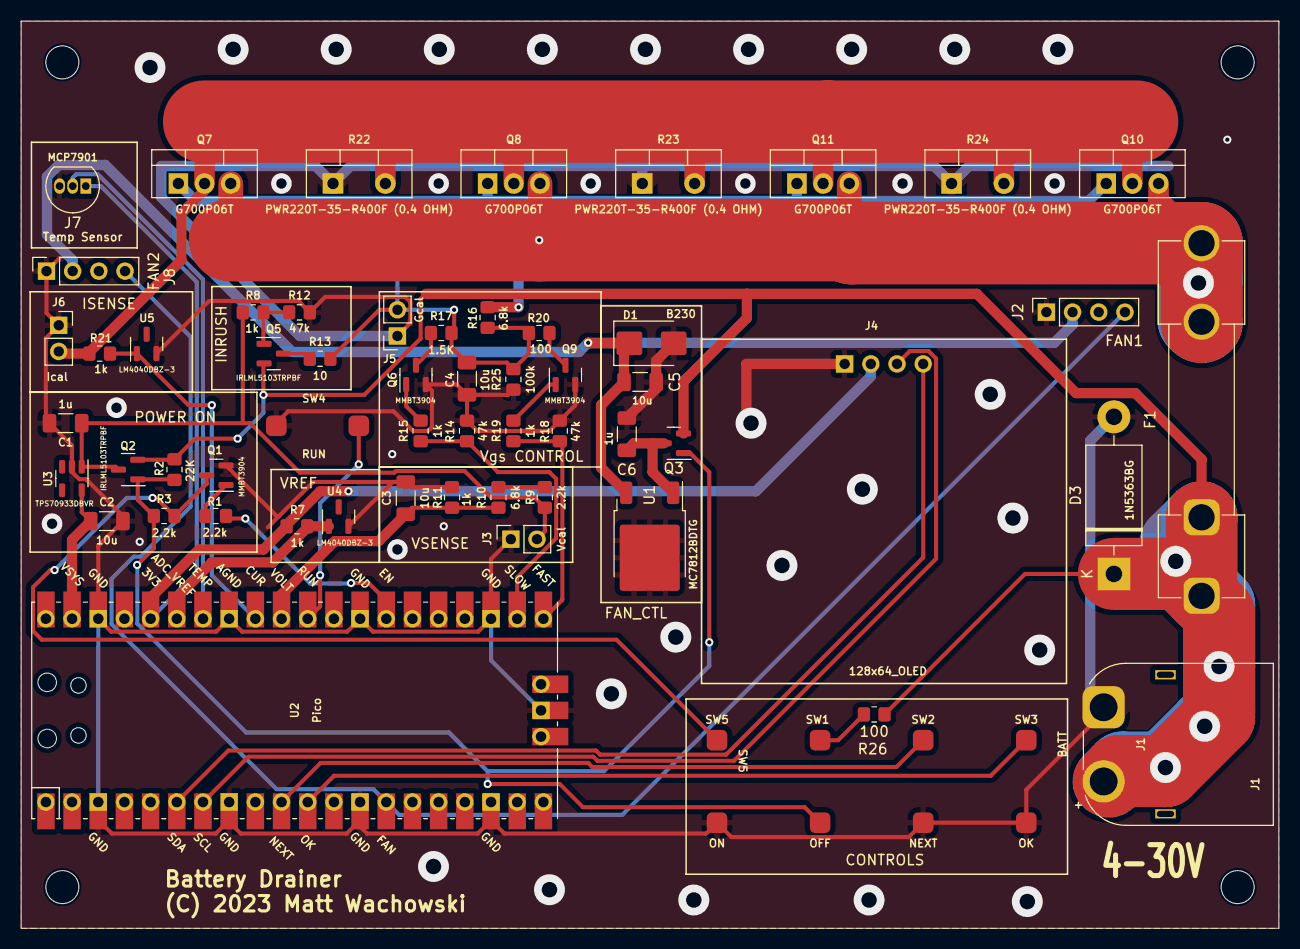
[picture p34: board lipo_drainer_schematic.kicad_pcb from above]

Board: 2 copper layers, 122.0 x 88.0 mm, 64 parts (0 on the bottom side), 34 nets.

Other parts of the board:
NEHOLE: MountingHole_3.2mm_M3
NWHOLE: MountingHole_3.2mm_M3
SEHOLE: MountingHole_3.2mm_M3
SWHOLE: MountingHole_3.2mm_M3

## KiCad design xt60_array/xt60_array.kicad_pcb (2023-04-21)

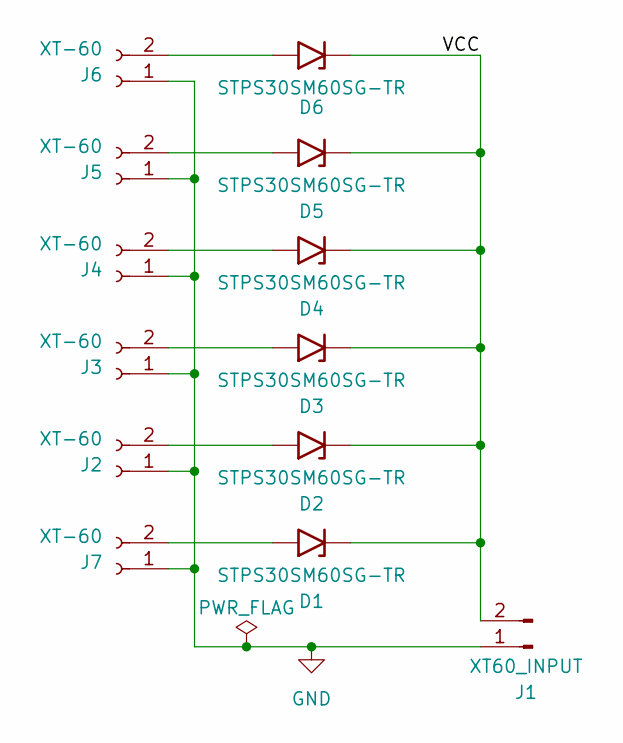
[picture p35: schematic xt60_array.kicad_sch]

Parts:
D1, D2, D3, D4, D5, D6: STPS30SM60SG-TR; TO-263-2_TabPin1_Alt
J1: XT60_INPUT; AMASS_XT60PW-F_1x02_P7.20mm_Horizontal
J2, J3, J4, J5, J6, J7: XT-60; AMASS_XT60-M_1x02_P7.20mm_Vertical

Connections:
/VCC: D1.1 (A1), D2.1 (A1), D3.1 (A1), D4.1 (A1), D5.1 (A1), D6.1 (A1), J1.2
GND: J1.1, J2.1, J3.1, J4.1, J5.1, J6.1, J7.1
unnamed: D1.2 (A2), J7.2
unnamed: D2.2 (A2), J2.2
unnamed: D3.2 (A2), J3.2
unnamed: D4.2 (A2), J4.2
unnamed: D5.2 (A2), J5.2
unnamed: D6.2 (A2), J6.2

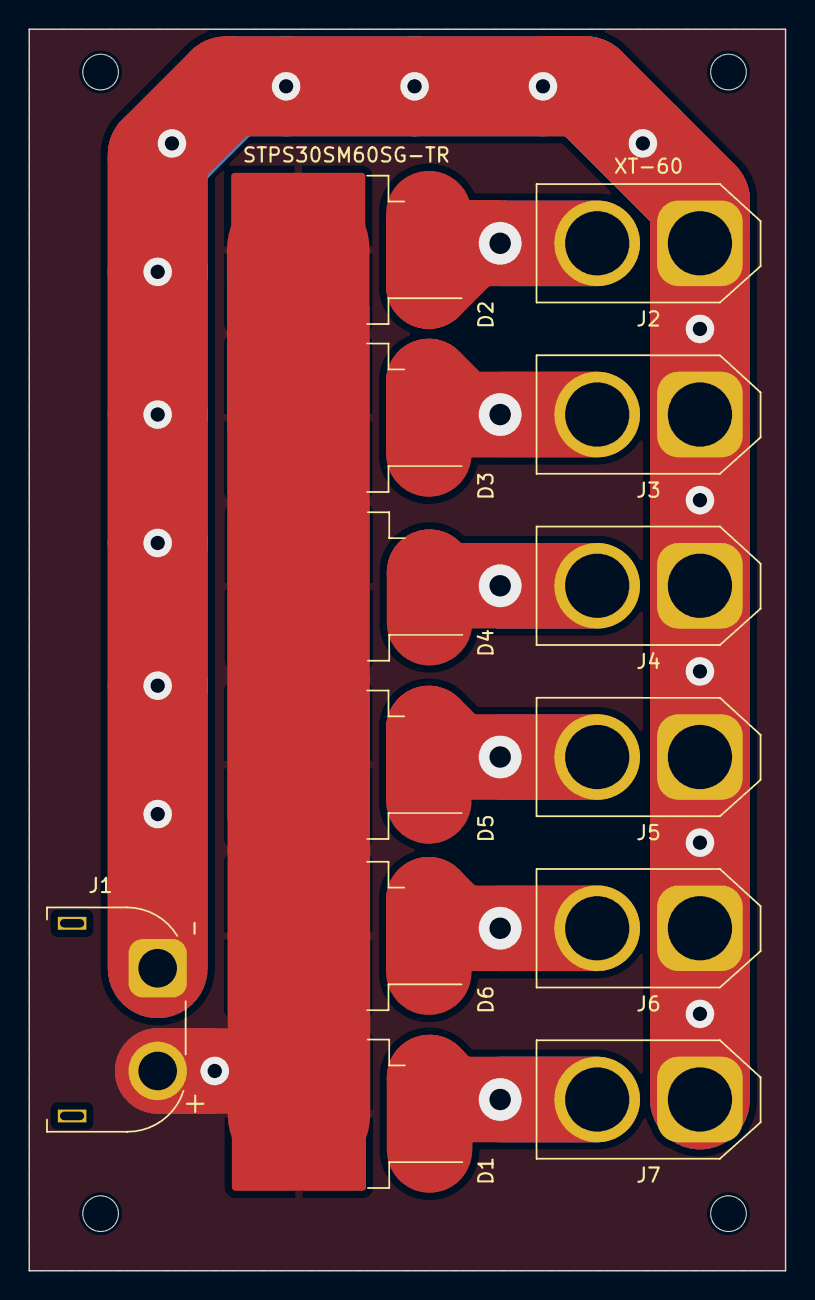
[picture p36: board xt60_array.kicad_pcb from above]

Board: 2 copper layers, 53.0 x 87.0 mm, 17 parts (0 on the bottom side), 8 nets.

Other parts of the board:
REF1, REF2, REF3, REF4: MountingHole_2.5mm

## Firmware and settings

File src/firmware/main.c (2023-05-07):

// LIPO Battery Drainer
//
// C 2023: Matt Wachowski

#include "buttons.h"
#include "console.h"
#include "current_sense.h"
#include "finished.h"
#include "damage_warning.h"
#include "draining_battery.h"
#include "fan_control.h"
#include "message.h"
#include "power.h"
#include "profile_selection.h"
#include "settings.h"
#include "state.h"
#include "temperature_sense.h"
#include "util.h"
#include "vgs_control.h"
#include "voltage_sense.h"

#include "pico/stdlib.h"
#include "hardware/adc.h"

#define LOOP_SLEEP_TIME_MS 20
#define LED_PIN PICO_DEFAULT_LED_PIN

struct Settings settings;
struct SharedState state;

static inline uint32_t uptime_ms() {
  return to_ms_since_boot(get_absolute_time());
}

static void init(void) {
  sleep_ms(50);  // Allow OLED voltage to settle
  power_hold();
  gpio_init(LED_PIN);
  gpio_set_dir(LED_PIN, GPIO_OUT);
  gpio_put(LED_PIN, 1);
  settings_load(&settings);
  console_init(&settings, &state);
  state_init(&state);
  buttons_init();
  vgs_control_init();
  fan_control_init();
  adc_init();
  voltage_sense_init();  // call adc_init() first
  current_sense_init();  // call adc_init() first
  temperature_sense_init();  // call adc_init() first
}

static void loop(void) {
  voltage_sense_update(&settings, &state);
  current_sense_update(&settings, &state);
  temperature_sense_update(&settings, &state);
  fan_control(&settings, &state);
  vgs_control(&settings, &state);
  buttons_update(&state);
  if ((state.state != DRAINING_BATTERY) || (state.fake_mv > 0)) {
    console_poll(state.vcal_adc_reading);
  }
  switch (state.state) {
    case PROFILE_SELECTION:
      profile_selection(&settings, &state);
      break;
    case CONDITION_MET_MESSAGE:
    case SETTINGS_MESSAGE:
    case ZERO_CELLS_MESSAGE:
      message(&state);
      break;
    case DAMAGE_WARNING:
      damage_warning(&state);
      break;
    case DRAINING_BATTERY:
      draining_battery(&settings, &state);
      break;
    case FINISHED:
      finished(&state, settings.global.finish_display);
      break;
    default:
      // if we are here, then the state is not yet implemented
      break;
  }
}

int main() {
  init();
  uint32_t frame_idx = 0;
  while (1) {
    state.uptime_ms = uptime_ms();
    loop();
    gpio_put(LED_PIN, frame_idx & 0x10 ? 1 : 0);
    ++frame_idx;
    const uint32_t tdelta = uptime_ms() - state.uptime_ms;
    if (tdelta < LOOP_SLEEP_TIME_MS) {
      sleep_ms(LOOP_SLEEP_TIME_MS - tdelta);
    } else {
      sleep_ms(1);
    }
  }
  return 0;
}

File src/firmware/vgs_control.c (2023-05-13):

#include "vgs_control.h"
#include "pico/stdlib.h"
#include "hardware/pwm.h"

#define FAST_GPIO 16
#define SLOW_GPIO 17
// These map to FAST_GPIO and SLOW_GPIO via the hardware spec.
// there are also pwm_gpio_to_PWM_SLICE and pwm_gpio_to_channel
// functions available but that create uneeded runtime variables
// for values that are static
#define PWM_SLICE 0
#define FAST_CHAN 0
#define SLOW_CHAN 1

#define MAX_FREQ 125000000
// The tradeoff
// Higher frequency = more stable vgs but less change resolution
// 10000 sets the divider at 12500, which allow for that many discrete steps
#define FREQ 10000
#define WRAP (MAX_FREQ / FREQ)

// how long to highlight a transient limiter
#define SHOW_LIMIT_MS 500

// duty cycle ranges from 0-32767
static inline uint16_t calc_level(uint16_t duty_cycle) {
  if (duty_cycle >= 32767) {
    return WRAP;
  }
  return (WRAP * (uint32_t)duty_cycle) / 32767;
}

void vgs_control_init(void) {
  gpio_set_function(FAST_GPIO, GPIO_FUNC_PWM);
  gpio_set_function(SLOW_GPIO, GPIO_FUNC_PWM);
  pwm_set_wrap(PWM_SLICE, WRAP);
  pwm_set_chan_level(PWM_SLICE, SLOW_CHAN, 0);
  pwm_set_chan_level(PWM_SLICE, FAST_CHAN, 0);
  pwm_set_enabled(PWM_SLICE, 1);
}

static void set_level(uint16_t new_level) {
  // note that values >= 32768 are capped at full-on within calc_level
  pwm_set_chan_level(PWM_SLICE, SLOW_CHAN, calc_level(new_level));
  if (new_level <= 32768) {
    pwm_set_chan_level(PWM_SLICE, FAST_CHAN, 0);
  } else {
    pwm_set_chan_level(
      PWM_SLICE, FAST_CHAN, calc_level(new_level - 32768));
  }
}

static uint8_t find_limiters(
  const struct Settings* settings, struct SharedState* state) {
    const struct ProfileSettings* ps =
        settings->profile + state->active_profile_index;

    const uint32_t deadline_ms = state->uptime_ms + SHOW_LIMIT_MS;
    uint8_t something_limited = 0;

    if (state->current_ma > ps->max_ma) {
      state->current_limited_ms = deadline_ms;
      something_limited = 1;
    }

    if (state->temperature_c > ps->max_celsius) {
      state->temperature_limited_ms = deadline_ms;
      something_limited = 1;
    }

    const uint32_t power = state->current_ma * state->loaded_mv / 1000000;
    if (power > ps->max_watts) {
      state->power_limited_ms = deadline_ms;
      something_limited = 1;
    }

    const uint16_t sag_mv =
      state->loaded_mv <= state->last_unloaded_sample_mv ?
      state->last_unloaded_sample_mv - state->loaded_mv :
      0;
    const uint16_t per_cell_sag_mv = sag_mv / state->cells;
    if (per_cell_sag_mv > ps->cell.max_vsag_mv) {
      state->voltage_sag_limited_ms = deadline_ms;
      something_limited = 1;
    }

    return something_limited;
}

static uint16_t calc_new_level(
  const struct Settings* settings, struct SharedState* state) {
  if (state->state != DRAINING_BATTERY) {
    return 0;
  }

  const struct ResponseSettings* r = &(settings->global.response);

  if (state->last_response_update_ms == 0) {
    // no time span to use yet
    state->velocity = r->max_velocity;
    return 0;
  }

  const uint8_t something_limited = find_limiters(settings, state);

  if (!something_limited) {
    if (state->velocity > 0) {
      // ok, but nothing is maximized.  example 10 -> 11
      state->velocity += r->acceleration;
      if (state->velocity > r->max_velocity) {
        state->velocity = r->max_velocity;
      }
    } else {
      // going negative when we are ok, reverse.  example -10 -> 9
      state->velocity = -state->velocity - r->deceleration;
      if (state->velocity < r->min_velocity) {
        state->velocity = r->min_velocity;
      }
    }
  } else {
    if (state->velocity > 0) {
      // too much. example: 10 -> -9
      state->velocity = -state->velocity + r->deceleration;
      if (state->velocity > -r->min_velocity) {
        state->velocity = -r->min_velocity;
      }
    } else {
      // have not gotten in back to an ok state yet. example -10 -> -11
      state->velocity -= r->acceleration;
      if (state->velocity < -r->max_velocity) {
        state->velocity = -r->max_velocity;
      }
    }
  }
  
  // now to actually add a chunk of velocity to the level
  // first, velocity is for a second of time.  Need to cut it down
  // to cover the actual time span
  const float time_span_ms = (float)(
    state->uptime_ms - state->last_response_update_ms);
  float scaled_v = state->velocity * time_span_ms / 1000.0;
  // scaled v is on a 0-100 scale and needs to be on a 0-65535 scale
  scaled_v = scaled_v * 65535.0 / 100.0;
  const float float_vgs_level = (float)(state->vgs_level) + scaled_v;
  if (float_vgs_level <= 0.0) {
    return 0;
  }
  if (float_vgs_level >= 65535.0) {
    return 65535;
  }
  return (uint16_t)(float_vgs_level);
}

void vgs_control(
  const struct Settings* settings, struct SharedState* state) {
  if (!state->is_sampling_voltage) {
    state->vgs_level = calc_new_level(settings, state);
    set_level(state->vgs_level);
  } else {
    set_level(0);
  }
  state->last_response_update_ms = state->uptime_ms;
}

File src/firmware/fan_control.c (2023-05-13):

#include "fan_control.h"
#include "pico/stdlib.h"
#include "hardware/pwm.h"

#define FAN_GPIO 10
// These map to FAN_GPIO via the hardware spec.
// there are also pwm_gpio_to_pwm_slice and pwm_gpio_to_channel
// functions available but that create uneeded runtime variables
// for values that are static
#define FAN_PWM_SLICE 5
#define FAN_CHAN 0

#define MAX_FREQ 125000000
#define FREQ 25000
#define WRAP (MAX_FREQ / FREQ)

// duty cycle ranges from 0-65535
static inline uint16_t calc_level(uint16_t duty_cycle) {
  return (WRAP * (uint32_t)duty_cycle) / 65535;
}

void fan_control_init(void) {
  gpio_set_function(FAN_GPIO, GPIO_FUNC_PWM);
  pwm_set_enabled(FAN_PWM_SLICE, 0);
  pwm_set_wrap(FAN_PWM_SLICE, WRAP);
  pwm_set_chan_level(
    FAN_PWM_SLICE, FAN_CHAN, 0);
  pwm_set_enabled(FAN_PWM_SLICE, 1);
}

static void set_pwm(const struct SharedState* state) {
  pwm_set_chan_level(
    FAN_PWM_SLICE, FAN_CHAN, calc_level(state->fan_level));
}

static uint16_t calc_new_level_by_temp(
  const struct Settings* settings, const struct SharedState* state) {
  const struct FanSettings* f = &(settings->global.fan);
  if (state->temperature_c < f->min_celsius) {
    return 0;
  }
  if (f->min_celsius >= f->max_celsius) {
    // this would create match errors below
    return 65535;
  }
  if (state->temperature_c > f->max_celsius) {
    // full power
    return 65535;
  }
  const uint32_t percent_base = (uint32_t)f->min_percent * 65535 / 100;
  const uint32_t percent_range = 65535 - percent_base;
  const uint32_t percent_add = (
    percent_range *
    (uint32_t)(state->temperature_c - f->min_celsius) /
    (f->max_celsius - f->min_celsius));
  return (uint16_t)(percent_base + percent_add);
}

static uint16_t calc_new_level_by_power(
  const struct Settings* settings, struct SharedState* state) {
  const struct FanSettings* f = &(settings->global.fan);
  uint16_avg_add(
    &(state->avg_power_watts),
    state->current_ma * state->loaded_mv / 1000000);
  const uint16_t power_watts = uint16_avg_get(&(state->avg_power_watts));
  if (power_watts < f->min_watts) {
    return 0;
  }
  if (f->min_watts >= f->max_watts) {
    // this would create match errors below
    return 65535;
  }
  if (power_watts > f->max_watts) {
    // full power
    return 65535;
  }
  const uint32_t percent_base = (uint32_t)f->min_percent * 65535 / 100;
  const uint32_t percent_range = 65535 - percent_base;
  const uint32_t percent_add = (
    percent_range *
    (uint32_t)(power_watts - f->min_watts) /
    (f->max_watts - f->min_watts));
  return (uint16_t)(percent_base + percent_add);
}

static inline int32_t calc_new_level(
  const struct Settings* settings, struct SharedState* state) {
    const uint16_t temp_level = calc_new_level_by_temp(settings, state);
    const uint16_t power_level = calc_new_level_by_power(settings, state);
    return temp_level > power_level ? temp_level : power_level;
}

void fan_control(
  const struct Settings* settings, struct SharedState* state) {
  if (state->is_sampling_voltage) {
    // don't make any changes while sampling voltage
    return;
  }
  int32_t level = calc_new_level(settings, state); 
  if (level != state->fan_level) {
    state->fan_level = level;
    set_pwm(state);
  }
}

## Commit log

2023-02-16 Started schematic
    [lipo_drainer_schematic.kicad_pcb, lipo_drainer_schematic.kicad_sch]
2023-02-27 Updated power circuit
    [lipo_drainer_schematic.kicad_sch]
2023-03-04 Enhanced schematic, but I'm probably not going with bulbs anymore
    [lipo_drainer_schematic.kicad_sch]
2023-03-04 Changed design to use PFETs
    [lipo_drainer_schematic.kicad_sch]
2023-03-05 Worked on calibration thoughts.
    [lipo_drainer_schematic.kicad_sch]
2023-03-05 Tweaked transistor in power design
    [lipo_drainer_schematic.kicad_sch]
2023-03-07 Added inrush current supression.
    [lipo_drainer_schematic.kicad_sch]
2023-03-07 Added fan controller
    [lipo_drainer_schematic.kicad_sch]
2023-03-07 Added flyback diode to fan control
    [lipo_drainer_schematic.kicad_sch]
2023-03-07 Switched fan control regulator to one with an enable pin.
    [lipo_drainer_schematic.kicad_sch]
2023-03-28 Changed transistor for less individual parts
    [lipo_drainer_schematic.kicad_sch]
2023-03-30 Added documenation for schematic.
    [lipo_drainer_schematic.kicad_sch]
2023-03-31 Adding more to the README
    [lipo_drainer_schematic.kicad_sch]
2023-04-01 more README work
    [lipo_drainer_schematic.kicad_sch]
2023-04-01 Fixed ERC warnings
    [lipo_drainer_schematic.kicad_sch]
2023-04-01 Added parts list
    [lipo_drainer_schematic.kicad_sch]
2023-04-01 Removed ineffective ON button
    [lipo_drainer_schematic.kicad_sch]
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2023-04-02 Started work on layout
    [lipo_drainer_schematic.kicad_pcb, lipo_drainer_schematic.kicad_sch]
2023-04-02 Added temperature sensor
    [lipo_drainer_schematic.kicad_pcb, lipo_drainer_schematic.kicad_sch]
2023-04-02 Added more net labels
    [lipo_drainer_schematic.kicad_pcb, lipo_drainer_schematic.kicad_sch]
2023-04-02 Added OLED footprint
    [lipo_drainer_schematic.kicad_pcb, lipo_drainer_schematic.kicad_sch]
2023-04-02 Change XT-60 connecter
    [lipo_drainer_schematic.kicad_pcb, lipo_drainer_schematic.kicad_sch]
2023-04-03 Starting to group PCB layout into logical sections.
    [lipo_drainer_schematic.kicad_pcb]
2023-04-03 Changed button definitions.
    [lipo_drainer_schematic.kicad_pcb, lipo_drainer_schematic.kicad_sch]
2023-04-03 Placed subblocks in PCB
    [lipo_drainer_schematic.kicad_pcb]
2023-04-03 Routed and added mounting holes.
    [lipo_drainer_schematic.kicad_pcb, lipo_drainer_schematic.kicad_sch]
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2023-04-04 Cleaned up almost all DRC warnings
    [lipo_drainer_schematic.kicad_pcb]
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2023-04-04 Changed OFF button to be directly connected to the FET
    [lipo_drainer_schematic.kicad_pcb, lipo_drainer_schematic.kicad_sch]
2023-04-05 Made Pico PCB labeloing specific
    [lipo_drainer_schematic.kicad_pcb]
2023-04-05 Added Zener inductance protection.
    [lipo_drainer_schematic.kicad_pcb, lipo_drainer_schematic.kicad_sch]
2023-04-06 Enlarge power vias, update schematic
    [lipo_drainer_schematic.kicad_pcb]
2023-04-09 Added motor BJT pulldown and redid ground planes
    [lipo_drainer_schematic.kicad_pcb, lipo_drainer_schematic.kicad_sch]
2023-04-11 Changed fan to PWMs
    [lipo_drainer_schematic.kicad_sch]
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2023-04-16 Missed some files on the last commit
    [xt60_array.kicad_pcb, xt60_array.kicad_sch]
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2023-04-21 Added gerber export for xt60 array.
    [lipo_drainer_schematic.kicad_pcb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]
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2023-04-27 Draft of vgs_control code.
    I didn't test it if would compile which means that it probably does not.
    [main.c]
2023-04-27 Fixes a couple of compile warmings.
    Amazingly, it compiled on the first try, but with a couple warnings.
    [main.c]
2023-04-27 Fixed get_num uint32 cast
    [main.c]
2023-04-28 vgs_control is now working.
    The main bug was feeding the wrong value into the slice calculation.
    I changed slice to be hard-coded since it's not going to change in
    the hardware anyway.
    [main.c]
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2023-04-29 Added some UI to readme
    [lipo_drainer_schematic.kicad_sch, xt60_array.kicad_sch]
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2023-05-01 Added CNC job for solder paste stencil
    [lipo_drainer_schematic-F_Paste.gbr]
2023-05-01 Added stencil for xt60 array
    [xt60_array-F_Paste.gbr]
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2023-05-04 Fixed USB output. Added heartbeat LED.
    [main.c]
2023-05-04 Added missing button interrupt handler
    [buttons.c]
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2023-05-04 Fix fan % formatting
    [console.c]
2023-05-04 Fixed maximum error value reporting
    [console.c]
2023-05-04 Fixed some console settings bugs.
    [console.c]
2023-05-04 Fixed up flash save
    * Use dynamic addresses based on sizeof(Settings), even though it's
    currentl not needed
    * disable interrupts to avoid a hang
2023-05-05 Fixed move dest size calculation
    [console.c]
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2023-05-06 Adds a 50ms startup delay.
    This will allow the OLED to get power and make sure that the EN low
    turn off doesn't lead to a reset -> EN high again (did not confirm this
    happens but it can in theory).
    [main.c]
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2023-05-07 voltage sampling bug fixes
    [vgs_control.c, voltage_sense.c]
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2023-05-12 Changed limit logic to hold the field inverted for 0.5 seconds.
    [vgs_control.c]
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2023-05-13 Revert "Using a 8 sample moving average on current."
    The update latency is making the tuning algorithm too unstable.
    This reverts commit 16eb5d84d4965ffdcd41e92defc5fa7b1cbc47c5.
    [current_sense.c, fan_control.c, vgs_control.c]
2023-05-13 Fixed regression where unloaded voltage samples no longer disabled PWM.
    [vgs_control.c]
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2023-05-13 Fixed typing bug that caused fet % to be mis displayed.
2023-05-13 Fixed issue where PWM that does not change does not get turned back on after a recal.
    [vgs_control.c]
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2023-05-13 Fixed overflow that would occur if the power/temp were way beyond the upper specified fan limit
    [fan_control.c]
2023-06-02 Starting 3D case model.
    [case.scad, heat_sink.scad]
2023-06-02 Added main board and pico.
    [case.scad]
2023-06-02 Added oled screen to pcb
    [main_pcb.scad]
2023-06-03 Added xt60 connector to main pcb
    [main_pcb.scad]
2023-06-03 Added buttons to main pcb.
    [main_pcb.scad]
2023-06-03 added fuse to main pcb
    [main_pcb.scad]
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2023-06-05 Added core include, which NopSCADlibn seems to need.
    [case.scad]
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2023-06-05 Started work on case.
    [case.scad, heat_sink.scad, main_pcb.scad]
2023-06-05 Added a fan shroud.
    [case.scad]
2023-06-05 Added Heat sink mount
    [case.scad]
2023-06-05 Made gaps in fan shroud for wiring
    [case.scad]
2023-06-05 Made the overall width based on the heat sink mount.
    [case.scad]
2023-06-05 renamed case to backside
    [case.scad]
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2023-06-05 Added frontside mounting holes/
    [case.scad]
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2023-06-06 Added frontside mounting holes
    [case.scad]
2023-06-06 Added front plate posts
    [case.scad]
2023-06-06 Added holeds to posts
    [case.scad]
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2023-06-06 Added hole for fan cable.
    [case.scad]
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2023-06-06 Made reset/boot holes smaller
    [case.scad]
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2023-06-06 Make the openscad library stand-alone
    [case.scad, heat_sink.scad, main_pcb.scad]
2023-06-06 Changed cable mounting offset to account for an angled connection
    [case.scad]
2023-06-07 Added glass plate projection
    [case.scad]
2023-06-10 Changed fron thickness based on real dimensions. Removed fron foot gap
    [case.scad]
2023-06-10 Added case model exports.
    [backside.3mf, case.scad, front_plate.dxf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]
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2023-07-01 Updated schematic to include FAN FET
    [lipo_drainer_schematic.kicad_pcb, lipo_drainer_schematic.kicad_sch]
